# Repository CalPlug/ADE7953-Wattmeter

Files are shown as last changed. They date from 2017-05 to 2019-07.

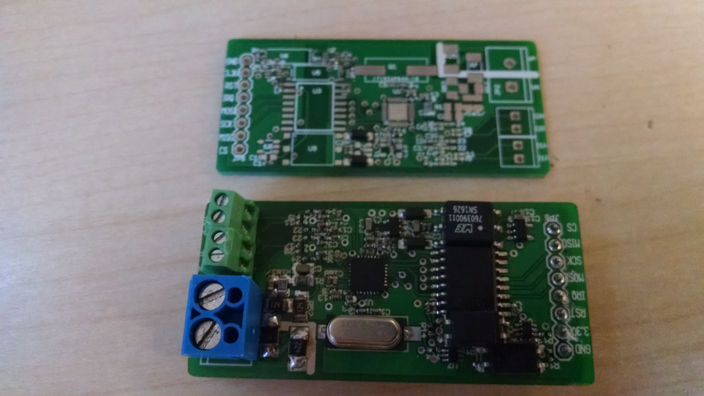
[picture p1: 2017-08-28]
Documents/PopulatedV2_Image.jpg

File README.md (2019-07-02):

# ADE7953-Wattmeter

Example Arduino compatable library for operating the Analog Devices ADE7953 Single-Phase AC Line measurement IC over SPI and I2C interfacing 

Arduino Uno / ESP8266 Library created by Umar Kazmi, Crystal Lai, and Michael Klopfer, Ph.D.

PCB v1 and v2 Board design by Damien Putignani (11/2016, 02/2017)

Version 3 PCB update by Yuxiang (Eric) Li	and Zihan (Bronco) Chen (11/2017)

Version 3.1 PCB update by Erica Deng (05/2018) - Isolation correction

Version 4 PCB (SPI / UART and I2C Variants) revision update by Erica Deng, Yongxi Li, Andy Begley, and Lifeng Liang (5/2018)

ESP32 SPI Extension Development by Luis Contreras as an extended part of the CalPlug EVSE Project (5/2018) - https://github.com/CalPlug/EVSE_Smart_Charger

University of California, Irvine - California Plug Load Research Center (CalPlug)

February 23, 2017 - SPI Library First Release

May 24, 2018 - I2C Library First Release, updated 12/2018

Updated PCB vervisions and notes 5/2019

Copyright (C) The Regents of the University of California, 2019

Released into the public domain under creative commons share-alike license. This is an example C++ library for Arduino for operating the ADE7953 Single-Phase AC Line measurement IC over SPI and tested with the Arduino Uno and C++ Arduino-style compiler for the Espressif ESP8266. This library in current form was shown to work with the Arduino Uno and the Espressif ESP8266.  See note below about Espressif ESP32 compatability - a working example is provided isn the ESP32 folder in this project.  This ESP32 extension example was developed by Luis Contreras as part of the CalPlug EVSE Project - https://github.com/CalPlug/EVSE_Smart_Charger and presented in this project as functional example working with the ESP32.

Installation
--------------------------------------------------------------------------------

To install this library, just place this entire folder as a subfolder in your
Arduino/lib/targets/libraries folder.
When installed, this library should look like:
Arduino/lib/targets/libraries/ADE7953              (this library's folder)
Arduino/lib/targets/libraries/ADE7953/ADE7953.cpp     (the library implementation file)
Arduino/lib/targets/libraries/ADE7953/ADE7953.h       (the library description file)
Arduino/lib/targets/libraries/ADE7953/examples     (the examples)
Arduino/lib/targets/libraries/ADE7953/readme.txt   (this file)

Note: as of 5/2018, the library has forked into an SPI and I2C variant that are tested with the ESP8266 and Atmel AVR.  There is also a known working SPI version for the ESP32.

Building
--------------------------------------------------------------------------------

After this library is installed, you can start the Arduino application.
You may see a few warning messages as it's built.
To use this library in a sketch, go to the Sketch | Import Library menu and select Test. This will add a corresponding line to the top of your sketch: #include <ADE7953.h>
To stop using this library, delete that line from your sketch.

Background of Operation
--------------------------------------------------------------------------------

The ADE7953 uses registers for communication.  Depending on the type, this can be an 8 bit, 16 bit, 24 bit or 32 bit register.  Communication of over 8 bits uses sequential bytes using typical SPI byte-wise communication.  There are redundancies in how registers are accessed via different bit values for registers.  For addresses, the same command may be represented in multiple bit versions (eg a 24bit or 32 bit). When you call on a certain address, the corresponding value is returned with the value bit size corresponding to the 24 or 32 bit address called on. The responding value returns as the function called and of the same bit size.  Refer to the documentation!  For Debug, the Serial Monitor runs at 115200 baudrate when the reporting DEBUG functionality is activated.  Uncomment IFDEF statements in the library for library operation debug. 

Usage
--------------------------------------------------------------------------------

There are several layers of functionality in the library.  Functions are defined to permit direct communication via registers of different bit sizes.  One can use the functions in this library for direct communication using the send and receive capability of the register calls or use direct functions.  The direct functions are also included. In order to access the functions, you must write in the Arduino file myADE7953.getFunction(), Function being the function you want such as Vrms or IrmsA (the different names of functions can be found in the .h file), while myADE7953 calls on the library. 

A sample I2C and SPI library for Arduino have been built and are present in this project.  At the present time the I2C is less developed than the SPI version.

Note: A varient of this project's code was shown to work on the Espressif ESP32, please see this project for more details:  https://github.com/CalPlug/EVSE_Smart_Charger

Calibration
--------------------------------------------------------------------------------
For a given hardware (register set) gain setting in the ADE7953 (we calibrate for each gain option in our final use code) we perform the calibration as inputs to each call of the decimalize() function for reported values:

0) Set a given HW gain value - this is important, each gain needs a different calibration set typically, also beware the input impedance can change for different hardware (register set) gain values!

1) We set values to gain = 1 and offset = 0 for each channel that will be calibrated.

2) Supply a known value and record returned values for all channels we are calibrating - this may be using a load that is measured by another calibrated meter so the current and voltage (or whatever basis parameters you care about are known).

3) In MS Excel (or Origin, Matlab, or any other program that can perform linear regression), we calculate the regression values (m (gain) and b (offset)) for y=mx+b, where y is the proper value, and x is the ADC returned value.  We take a number of measurements across the linear measurement range.  Typically the ADCs on this IC are very linear.  Keep in mind the r^2 value for the fitting is not all that matters - the distance between the fit line and the expected values (the residuals) will give you an idea of calibration gross accuracy across your measurement range. 

4) Enter gain and offset regression values for each calibrated input channel (overwriting the initial gain=1 and offset=0 values used in the calibration process), recompile, and test.

5) Repeat calibration process if your outputted values do not now closely match your expected measured values.

A sample calibration spreadsheet is provided:  https://github.com/CalPlug/ADE7953-Wattmeter/blob/master/library/LinearCalibrationCalculator.xls

Demo
--------------------------------------------------------------------------------

When connecting a 80-Watt Lightbulb with a 110V AC, 60HZ, source and using our demo code, the serial monitor reads out the following approximate measurements from the current sensor:

Vrms (V): 110

IrmsA (mA): 718

Apparent Power A (mW): 80000

Active Power A (mW): 80000

Reactive Power A (mW): 4100

Power Factor (div 100): 99.90

Active Energy A (hex): 5132 

See initial checkout instructions for the PCB for expected demo code output:  https://github.com/CalPlug/ADE7953-Wattmeter/blob/master/Documents/Construction%20of%20Wattmeter.pdf

Physical Demo Board
----------
This design is provided without any warranty or assumption of liability.  This project involves the use of mains voltage.  We have no idea how well you can reporduce this design: we assume no liability for your implementation or usage mistakes! Please construct and use at your own risk.

This folder contains all the files required to construct a fully isolated ADE7953 wattmeter board that uses SPI or UART communication (see IC Datasheet). Please refer to the README inside the folder for more details on using the files.  The Version 3 supercedes the Version 2 board.  Version 1 of this PCB was an internally produced breadboard evaualtion version of this design.  It was created only to be proceeded by Version 2.  In the Version 2 (preliminary release) revision, there is no tri-state on the MISO line on the external side of the isolation chipset. Because of this, the board works properly when it is the only device on the SPI bus. If more devices are used on the same SPI bus, the CS line (inverted) must be used to drive a tristate to isolate the MISO line from this board.  The RESET and IRQ lines can be left unconnected for general operation of the board - the ADE7953 reset line is held HIGH by a pullup by default.  The minimum connections required are the data and power lines.  Be cognizent that flipped L and N in this design can result in safety concerns - the neutral volatage should be very close to ground.  This issue is mediated in the following design revisions.  The Version 2 board has the neutral connected to the isolated ground.  In bench testing, this design worked well, but in general usage, several catostrophic board failures resulted (not that crazy on our part: look at how the Analog Devices datasheet and AD demo boards are wired :) ).  

Accordingly, a safer design was developed (Version 3).  As previously stated, the Version 2 of the board does not allow for multiple devices to be used on the SPI as the MISO line is held low when communication has ended (the isolator is always enabled, causing this).  In the updated Version 3, an inverted gate tri-state buffer allows proper SPI usage with multiple devices and resistor chains are used to isolate the neutral from the ground in case of the neutral having the voltage become raised substantially above the ground (or flipped with the line).  A ground isolation issue was resolved in Version 3.1 to improve the safety of the board further.  In Version 3.1 and forward there is full separation of the grounds on the isolated and non isolated sides of the board.

The Version 4 of this board allows use of a multiplexer for line and neutral inputs along with two current measurement coils to allow GFI detection.  The isolator configuration allows for fullly independant ground isolation.  The a jumper on this board (position 1-2, or position 2-3) allows the static setting of the line, or a pin (SELECT) can be used to toggle the voltage input being read (used with ground fault detection - full GFI implementation requires an interruptter!).  This can be used to set a single input pin for the line to measure against ground without needing a dedicated microcontroller pin or external connection.  Mind the phasing between the two coils if two CTs are used for GFI detection.  Implementation of the GFI detection and interruption with this design was demonstrated in this project using the Espressif ESP32: https://github.com/CalPlug/EVSE_Smart_Charger   The default version of this board (Version 4) is also UART compatable (see included documentation) in addition to SPI.  But the bidirectional nature of I2C prevents this working with the current isolation scheme.  An alternative design (Version 4 I2C) is also provided which permits I2C interfacing using the same board format.

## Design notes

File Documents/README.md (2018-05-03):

Note:

The boards (versions 2-4) will take 3.3 to 5V as an input DC power in per our tests.  More efficient operation is at 3.3V and what we typically use.  Preference to use 3.3V logic voltages but 5V tolerant - but output logic voltage will match supply!  Be Careful!
Mind the isolation capability of the isolator - avoid ground loops and large differences between grounds.  On V2 be careful as to the L/N orrientation for the AC input.  A second resistor divider network on V3 provides more protestion.  V4 uses a multiplexer in place of a set of networks to allow Ground Fault (GF) detection as part of a potential GFI system.

File Manifest: 

Wattmeter_v2_gerber_files.zip
------------------------------
Upload this .zip file to https://www.smart-prototyping.com/PCB-Prototyping.html to order PCBs for populating.

wattemeterBOM.xlsx (in Wattmeter_V2 Folder)
-------------------
This spreadsheet is the bill of materials for populating the PCBs.

Wattmeter_v2.brd & Wattmeter_v2.sch (in Wattmeter_V2 Folder)
------------------------------------
Open them with EagleCAD and print them out, and have them nearby while populating the PCBs to know what goes where.

Construction of Wattmeter.pdf and Stilting Components to a PCB_in_V2_MJKedit.docx and WattmeterCheckoutGuide
-----------------------------
Documents showing assembly and test procedures.
Shows what a finished Wattmeter looks like, and has some important tips on populating the PCBs.  

NOTE: There is no tri-state on the MISO line in board Version 2.  This is added into the next board revision (Board version 3.  Because of this, the board works properly when it is the only device on the SPI bus.  If more devices are used on the same SPI bus, the CS line (inverted) must be used to drive a tristate to isolate the MISO line from this board!!! 

PopulatedV2_Image.jpg
-----------------------------
Image of the blank and populated PCB of the wattmeter

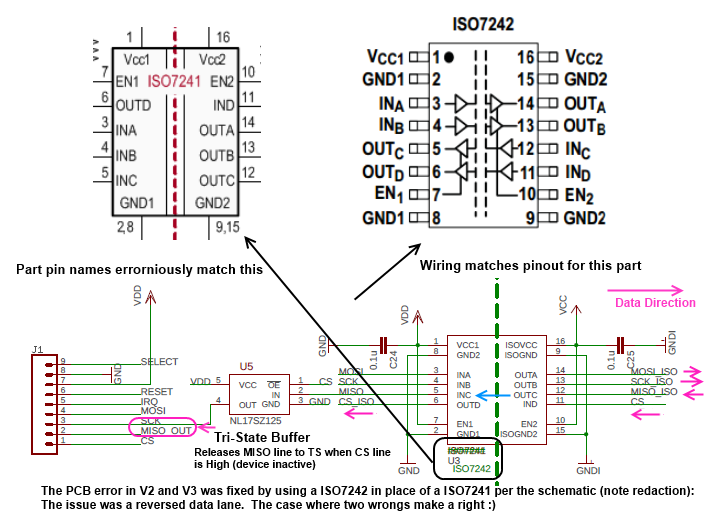
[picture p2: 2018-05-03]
Documents/V2_V3Error.png

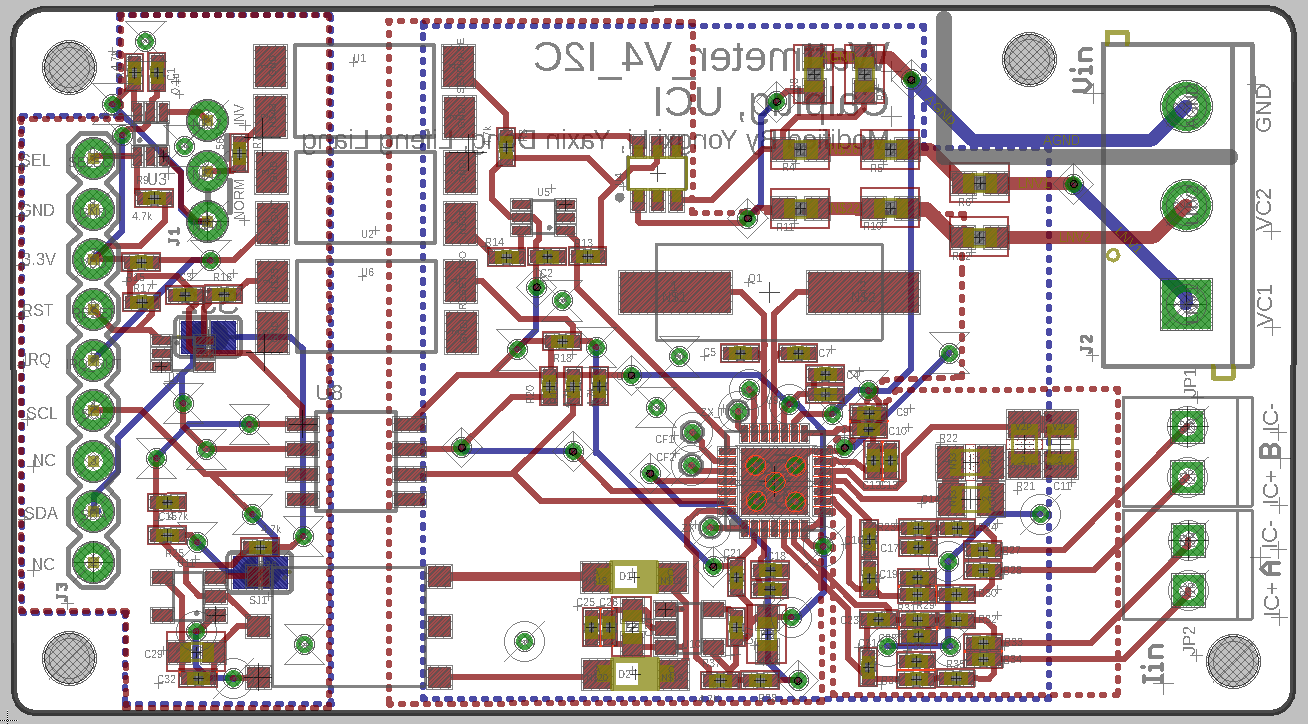
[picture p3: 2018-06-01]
documents/Wattmeter_V4/Wattmeter_V4_I2C.PNG

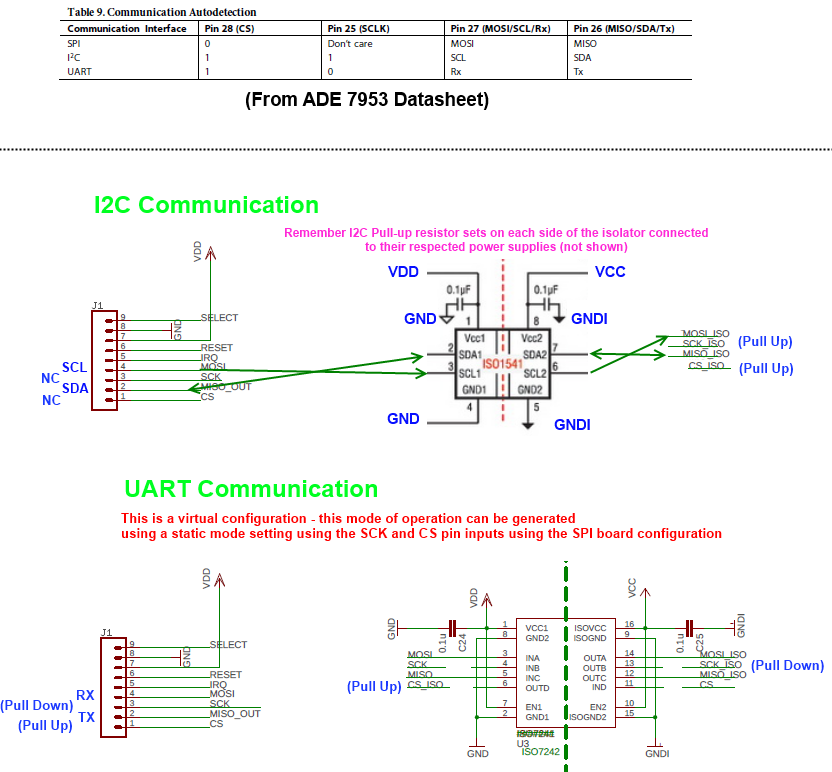
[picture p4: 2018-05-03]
pcb_layout/Wattmeter_V4/UARTandSPICom.png

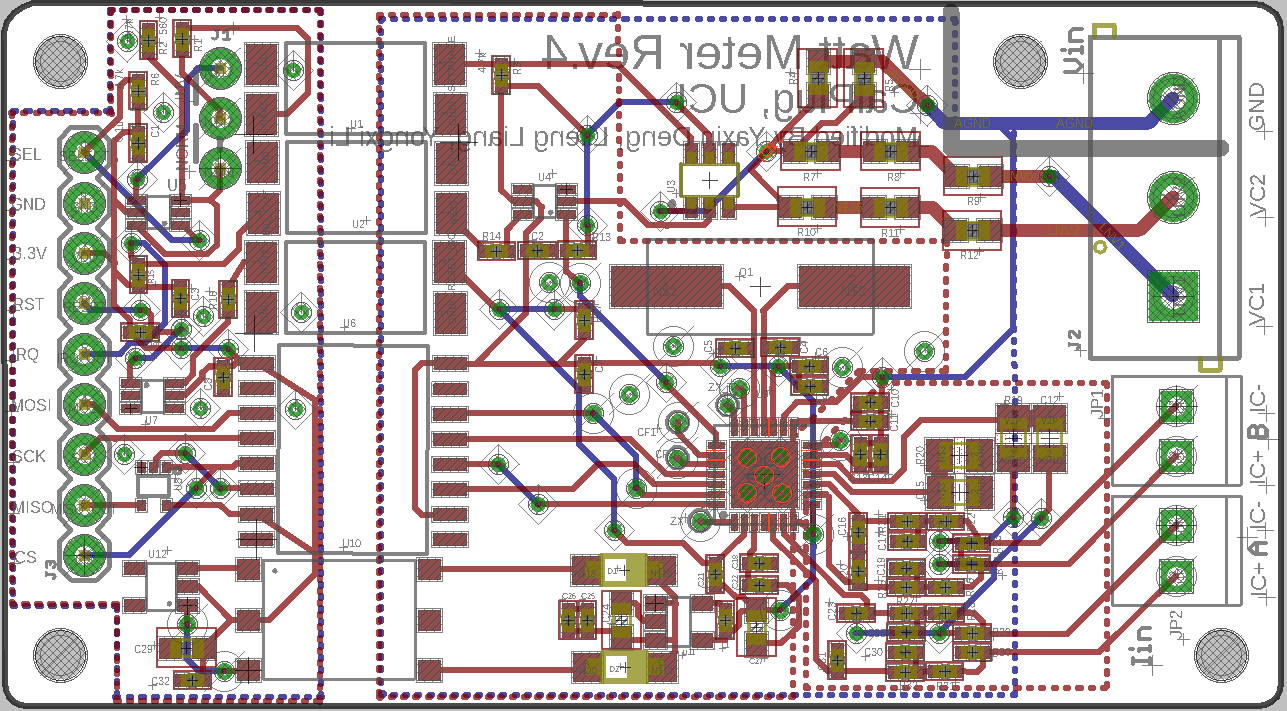
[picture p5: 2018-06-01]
documents/Wattmeter_V4/Wattmeter_V4.PNG

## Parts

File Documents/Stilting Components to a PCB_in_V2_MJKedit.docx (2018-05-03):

Stilting Components to a PCB

Jazmin Villegas

California Plug Load Research Center

1. What is stilting?

Stilting is the process of attaching/soldering legs to a component in order to elevating the component by a desired height. This is a process to allow testing of a component where the packaging was not intended for mounting on the PCB that mounting will occur. Typically the PCB was intended for a smaller package component. Vertical height is used to compensate for lack of lateral space with component placement. In this case two opto-isolators are too close to be mounted properly. Both parts are stilted to permit mounting without interference.

2. Why so you need to stilt?

U5 U6

When applying components to a printed circuit board (PCB) you may find that there is a crowd of components in a certain area, resulting in component-component interference. This may not allow you to use the conventional methods of soldering or the soldering paste as you have intended. As shown in the picture on the right, components U6 and U5 had been placed in close proximity to one another, not allowing for either to be placed properly on the pads intended for connections to this component. With stilting we will be able to elevate one component (or both) allowing for proper connectivity of all components.

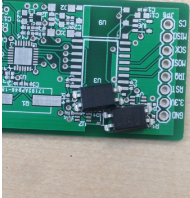
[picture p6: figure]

Figure 1: Neither U6 nor U5 are able to align with the pads on the PCB. Both components have four legs.

3. How to Stilt.

To beginning the process of stilting you will need to make sure your component is sanitized and fully functional.

  i. First, we will begin by applying a metal stilt to each leg. Use the cut leads from a 1/4th watt resistor as the interconnect leads. Having malleable stilts allows you to freely adjust your component for the best allignment to pads while preventing interference on the board. These legs are generally tin-clad copper wire. When applying the metal, you would like to measure how much height is needed to allow best allignment. In our case, we only needed one component stilted with the height being more than its bordering components. Make sure all legs are cut to the proper height before soldering, a final trimming will occur after soldering each leg to the part to mount.
  ii. After you have measured and trimmed all the stilts for your component, you can now solder each stilt to a corresponding leg. Use tweezers to hold part when soldering to prevent burs. Tin both the component and the wire before performing the joining via soldering. When you finish soldering check the height of the stilts once again, if the stilts have shifted in height cut the appropriate amount of metal from the stilts so the component can lay on a flat surface. The stilts should align with the pads and the component should sit flat on the stilts. Do not mount to some pads and warp the other legs to meet remaining pads. It is easy to tear pads off the PCB when doing this.
  iii. Next you would like to position your component on your PCB ensuring that all stilts are placed on top of the corresponding solder pads. Soldering the stilt to the board will be a bit challenging. You will need to quickly apply solder each leg, the heat from the solder iron may loosen your any previous soldering you have completed. If this does happen reapply the loose piece(s) once again. Once you have completed applying all legs you would like to repeat this process for any other parts you would like stilted or continue soldering the rest of your other components.

Stilted Component

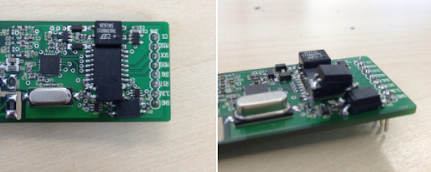
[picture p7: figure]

Figure 2: A finished PCB after stilting. The picture on the left is the top view. The picture on the right is the side view. Here you notice the component we have stilted. It is elevated above the components in its proximity allowing for the other components to lay flat on the PCB.

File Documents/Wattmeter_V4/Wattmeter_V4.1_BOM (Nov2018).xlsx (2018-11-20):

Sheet: DIGIKEY
Qty | Value | Device | Package | Parts | DIGIKEY | Unit Price | Total quantity | Total price
11 | 0.1u | 0402-CAP | 0402-CAP | C1,C2,C3,C7,C8,C9,C11,C14,C18,C26,C32 | http://www.digikey.com/product-detail/en/GRM155R61A104KA01D/490-1318-1-ND/587923 | 0.007 | 110 | 16.599
2 | 20p | 0402-CAP | 0402-CAP | C4,C5 | http://www.digikey.com/product-detail/en/murata-electronics-north-america/GJM1555C1H200FB01D/490-11204-1-ND/5333044 | 0.12 | 20 | 2.4
4 | 4.7u | 0402-CAP | 0402-CAP | C6,C10,C13,C22 | http://www.digikey.com/product-detail/en/GRM155R60J475ME87D/490-5408-1-ND/2175215 | 0.126 | 40 | 5.4
2 | 0.033uF | C-EUC0805K | C0805K | C12,C15 | http://www.digikey.com/product-detail/en/samsung-electro-mechanics-america-inc/CL05B333KO5NNNC/1276-1177-1-ND/3889263 | 0.028 | 20 | 0.56
8 | 33n | 0402-CAP | 0402-CAP | C16,C17,C19,C20,C23,C28,C30,C31 | http://www.digikey.com/product-detail/en/samsung-electro-mechanics-america-inc/CL05B333KO5NNNC/1276-1177-1-ND/3889263 | 0.162 | 80 | 12.96
2 | 1u | 0402-CAP | 0402-CAP | C21,C25 | https://www.digikey.com/products/en?keywords=445-9082-1-ND | 0.12 | 20 | 2.4
2 | 10uF | C-USC0603 | C0603 | C24,C27 | https://www.digikey.com/product-detail/en/murata-electronics-north-america/GRM188R60J106ME47D/490-3896-1-ND/965938 | 0.14 | 20 | 2.8
1 | 10uF TANT | C-USC0603 | C0603 | C29 | https://www.digikey.com/product-detail/en/vishay-sprague/T58MM106M6R3C0500/718-2110-1-ND/5844728 | 0.528 | 10 | 5.28
2 | MBR0520LT | MBR0520LT | SOD123 | D1,D2 | https://www.digikey.com/product-detail/en/micro-commercial-co/MBR0520-TP/MBR0520TPMSCT-ND/717365 | 0.292 | 20 | 5.84
12 |  | CONN_09 | 1X3, 1X9 | J1,J3 | https://www.digikey.com/products/en?mpart=PREC040SAAN-RC&v=35 | 0.51 | 3 | 1.53
1 |  | CONN_03-SCREW-5MM | SCREWTERMINAL-5MM-3 MULTI | J2 | https://www.digikey.com/product-detail/en/phoenix-contact/1729021/277-1237-ND/260605 | 1.507 | 10 | 15.07
2 |  | M022.54MM_SCREWTERM | 1X02_2.54_SCREWTERM | JP1,JP2 | https://www.digikey.com/product-detail/en/on-shore-technology-inc/OSTVN02A150/ED10561-ND/1588862 | 0.568 | 20 | 11.36
1 | 15nH | IND0402 | 0402-RES | L1 | https://www.digikey.com/product-detail/en/murata-electronics-north-america/LQG15HS15NJ02D/490-2625-1-ND/662905 | 0.061 | 10 | 0.61
1 | QUARTZ_3.58M_2PIN | QUARTZ_3.58M_2PIN | HC-49S | Q1 | https://www.digikey.com/product-detail/en/txc-corporation/9C-3.579545MBBK-T/887-2450-1-ND/4475440 | 0.303 | 10 | 3.03
3 | 560 | 0402-RES | 0402-RES | R1, R14, R16 | http://www.digikey.com/product-detail/en/panasonic-electronic-components/ERJ-2RKF5600X/P560LCT-ND/1746701 | 0.043 | 30 | 1.29
7 | 4.7k | 0402-RES | 0402-RES | R2,R3,R6,R13,R15,R17,R18 | https://www.digikey.com/product-detail/en/panasonic-electronic-components/ERJ-2GEJ472X/P4.7KJCT-ND/147025 | 0.029 | 90 | 2.61
2 | 4.7k | RESISTOR0603-RES | 0603-RES | R4,R5 | https://www.digikey.com/product-detail/en/vishay-dale/TNPW06034K75BEEA/TNP4.75KAATR-ND/1606844 | 0.116 | 20 | 2.32
2 | 55k | RESISTOR0603-RES | 0603-RES | R7,R10 | https://www.digikey.com/products/en?keywords=RMCF0603FT54K9CT-ND | 0.017 | 20 | 0.34
4 | 100k | RESISTOR0603-RES | 0603-RES | R8,R9,R11,R12 | https://www.digikey.com/products/en?keywords=P100KHCT-ND | 0.063 | 40 | 2.52
2 | 1k | R-EU_ | C0805K@1 | R19,R20 | https://www.digikey.com/products/en?keywords=A106056CT-ND | 0.032 | 20 | 0.64
4 | 1k | 0402-RES | 0402-RES | R21, R25, R27, R32 | https://www.digikey.com/products/en?keywords=P1.00KLCT-ND | 0.043 | 40 | 1.72
4 | 100 | 0402-RES | 0402-RES | R22,R26, R28,R31 | http://www.digikey.com/product-detail/en/panasonic-electronic-components/ERJ-2RKF1000X/P100LCT-ND/194126 | 0.043 | 40 | 1.72
4 | 51 | 0402-RES | 0402-RES | R23,R24,R29,R30 | http://www.digikey.com/product-detail/en/panasonic-electronic-components/ERJ-2RKF51R0X/P51.0LCT-ND/1746700 | 0.043 | 40 | 1.72
3 | PS2505 | PS2505 | PS2505 | U1, U2,U6 | http://www.digikey.com/product-detail/en/cel/PS2505L-1-F3-A/PS2505L-1-F3-ACT-ND/3646235 | 0.732 | 30 | 21.96
1 | SN74LVC1G3157DBVR | SN74LVC1G3157DBVR | SOT-23-6 | U3 | https://www.digikey.com/products/en?keywords=296-14908-1-ND | 0.276 | 10 | 2.76
3 | SN74LVC | SN74LVC | DCKT | U4, U5,U7 | http://www.digikey.com/product-detail/en/texas-instruments/SN74LVC2G14DCKT/296-26619-1-ND/2255077 | 0.869 | 30 | 26.07
1 | NL17SZ125 | NL17SZ125 | NL17SZ125 | U8 | https://www.digikey.com/product-detail/en/on-semiconductor/NL17SZ125DFT2G/NL17SZ125DFT2GOSCT-ND/1139962 | 0.276 | 10 | 2.76
1 | ADE7953 | ADE7953 | 28-WFQFN | U9 | http://www.digikey.com/product-detail/en/analog-devices-inc/ADE7953ACPZ/ADE7953ACPZ-ND/2700176 | 3.594 | 10 | 35.94
1 | ISO7241 | ISO7241 | 16-SOIC | U10 | http://www.digikey.com/product-detail/en/texas-instruments/ISO7241CDWR/296-37636-1-ND/4833880 | 4.466 | 10 | 44.66
1 | PAM2305 | PAM2305 | TSOT25 | U11 | http://www.digikey.com/product-detail/en/diodes-incorporated/PAM2305AAB330/PAM2305AAB330DICT-ND/5267111 | 0.51 | 10 | 5.1
1 | SN6501 | SN6501 | SOT-23-5 | U12 | http://www.digikey.com/product-detail/en/texas-instruments/SN6501DBVR/296-37700-1-ND/4833928 | 1.801 | 10 | 18.01
1 | TRANSFO_3.3 | TRANSFO_3.3 | TRANSFO_3.3 | U13 | http://www.digikey.com/product-detail/en/wurth-electronics-midcom/760390011/732-4455-1-ND/3831291 | 1.71 | 10 | 17.1
 |  |  |  |  |  |  | TOTAL PRICE: | 275.079

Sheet: AMAZON
Qty | Value | Device | Package | Parts | Amazon | Unit Price | Total quantity | Total price
1 |  | jumper cap |  |  | https://www.amazon.com/gp/offer-listing/B00008VF46/ref=dp_olp_new_mbc?ie=UTF8&condition=new | 6 | 1 | 6
 |  |  |  |  |  |  | total price | 6

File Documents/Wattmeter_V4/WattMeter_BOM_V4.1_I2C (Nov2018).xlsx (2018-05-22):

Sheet: Feuil1
Qty | Value | Device | Package | Parts | DIGIKEY | Unit PRICE | Total quantity | Total price
2 |  | M022.54MM_SCREWTERM | 1X02_2.54_SCREWTERM | JP1,JP2 | ED10561-ND | 0.568 | 20 | 11.36
11 | 0.1u | 0402-CAP | 0402-CAP | C1,C2,C3,C6,C8,C10,C13,C15,C18,C25,C32 | 445-1265-6-ND | 0.08755 | 110 | 9.6305
4 | 100 | 0402-RES | 0402-RES | R24,R30,R32,R35 | P100LCT-ND | 0.043 | 40 | 1.72
2 | 10uF | C-USC0603 | C0603 | C24,C27 | 490-3896-1-ND | 0.14 | 20 | 2.8
1 | 15nH | IND0402 | 0402-RES | L1 | 445-3061-1-ND | 0.052 | 10 | 0.52
4 | 1k | 0402-RES | 0402-RES | R23,R29,R31,R36 | P1.00KLCT-ND | 0.043 | 40 | 1.72
2 | 1u | 0402-CAP | 0402-CAP | C21,C26 | 445-9082-1-ND | 0.12 | 20 | 2.4
2 | 20p | 0402-CAP | 0402-CAP | C5,C7 | 490-11204-1-ND | 0.162 | 20 | 3.24
2 | 0.033uF | C-EUC0805K | C0805K | C11,C14 | 445-2675-2-ND | 0.359 | 20 | 7.18
4 | 4.7u | 0402-CAP | 0402-CAP | C4,C9,C12,C22 | 399-5499-1-ND | 0.28 | 40 | 11.2
4 | 51 | 0402-RES | 0402-RES | R27,R28,R33,R34 | P51.0LCT-ND | 0.043 | 40 | 1.72
3 | 560 | 0402-RES | 0402-RES | R7,R14,R16 | P560LCT-ND | 0.043 | 30 | 1.29
1 | ADE7953 | ADE7953 | 28-WFQFN | U9 | ADE7953ACPZ-ND | 3.594 | 10 | 35.94
2 | MBR0520LT | MBR0520LT | SOD123 | D1,D2 | MBR0520LCT-ND | 0.323 | 20 | 6.46
1 | PAM2305 | PAM2305 | TSOT25 | U10 | PAM2305AAB330DICT-ND | 0.51 | 10 | 5.1
1 | QUARTZ_3.58M_2PIN | QUARTZ_3.58M_2PIN | HC-49S | Q1 | 887-2450-1-ND(out of stock) | 0.303 | 10 | 3.03
1 | SN6501 | SN6501 | SOT-23-5 | U11 | 296-37700-1-ND | 1.801 | 10 | 18.01
3 | SN74LVC | SN74LVC | DCKT | U3,U5,U7 | 296-26619-1-ND | 0.869 | 30 | 26.07
1 | TRANSFO_3.3 | TRANSFO_3.3 | TRANSFO_3.3 | U12 | 732-4455-1-ND | 1.71 | 10 | 17.1
13 | 4.7k | 0402-RES | 0402-RES | R1,R3,R9,R13,R15,R17,R18,R19,R20,R25,R26,R37,R38 | P10.0KLCT-ND | 0.0176 | 130 | 2.288
1 | 10uF-TANT | C-USC0603 | C0603 | C29 | 718-2110-1-ND | 0.528 | 10 | 5.28
8 | 33nF | 0402-CAP | 0402-CAP | C16,C17,C19,C20,C23,C28,C30,C31 | 399-8964-6-ND | 0.4795 | 80 | 38.36
1 | JUMPER3 | JUMPER3 | 1X03 | J1,J3 | S1012EC-40-ND | 0.454 | 10 | 4.54
1 |  | CONN_03-SCREW-5MM | SCREWTERMINAL-5MM-3 | J2 | 277-1237-ND | 1.507 | 10 | 15.07
2 | 4.7k | RESISTOR0603-RES | 0603-RES | R2,R8 | A106050DKR-ND | 0.368 | 20 | 7.36
2 | 55k | RESISTOR0603-RES | 0603-RES | R4,R11 | RMCF0603FT54K9CT-ND | 0.017 | 20 | 0.34
4 | 100k | RESISTOR0603-RES | 0603-RES | R5,R6,R10,R12 | P100KHCT-ND | 0.063 | 40 | 2.52
2 | 1k | R-EU_ | C0805K@1 | R21,R22 | A106056CT-ND | 0.032 | 20 | 0.64
3 | PS2505 | PS2505 | PS2505 | U1,U2,U6 | PS2505L-1-F3-ACT-ND | 0.606 | 30 | 18.18
1 | SN74LVC1G3157DBVR | SN74LVC1G3157DBVR | SOT-23-6 | U4 | 296-14908-1-ND | 0.276 | 10 | 2.76
1 | ISO1541 | ISO1541 | ISO1541 | U8 | 296-34872-1-ND | 3.883 | 10 | 38.83
 |  |  |  |  |  |  | Total: | 302.66

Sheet: Feuil1 (2)
Qty | Value | Device | Package | Parts | DIGIKEY | Unit PRICE for 10 | Total quantity (15 boards) | Qty in stock | Qty to buy | Total price
2 |  | M022.54MM_SCREWTERM | 1X02_2.54_SCREWTERM | JP3, JP4 | http://www.digikey.com/product-detail/en/on-shore-technology-inc/OSTVN02A150/ED10561-ND/1588862 | 0.568 | 30 | 9 | 21 | 11.928
1 |  | M025MM | SCREWTERMINAL-5MM-2 | JP2 | https://www.digikey.com/product-detail/en/1729018/277-1236-ND/260604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 | 0.955 | 15 | 4 | 11 | 10.505
1 |  | M08 | 1X08_ROUND | JP5 | no componant | 0 | 15 |  | 15 | 0
10 | 0.1u | 0402-CAP | 0402-CAP | C4, C8, C14, C16, C18, C20, C24, C25, C26, C27 | http://www.digikey.com/product-detail/en/GRM155R61A104KA01D/490-1318-1-ND/587923 | 0.014 | 150 |  | 150 | 2.1
4 | 100 | 0402-RES | 0402-RES | R21, R22, R23, R24 | http://www.digikey.com/product-detail/en/panasonic-electronic-components/ERJ-2RKF1000X/P100LCT-ND/194126 | 0.028 | 60 | 37 | 23 | 0.644
5 | 10k | 0402-RES | 0402-RES | R2, R3, R13, R14, R15 | https://www.digikey.com/product-detail/en/yageo/RC0402FR-0710KL/311-10.0KLRCT-ND/729470 | 0.014 | 75 |  | 75 | 1.05
2 | 10uF | C-USC0603 | C0603 | C22, C23 | https://www.digikey.com/product-detail/en/murata-electronics-north-america/GRM188R60J106ME47D/490-3896-1-ND/965938 | 0.123 | 30 |  | 30 | 3.69
2 | 120k | R-EU_M1206 | M1206 | R12, R52 | http://www.digikey.com/product-detail/en/yageo/RC1206JR-07120KL/311-120KERCT-ND/732163 | 0.024 | 30 | 19 | 11 | 0.264
1 | 15nH | IND0402 | 0402-RES | L1 | https://www.digikey.com/product-detail/en/murata-electronics-north-america/LQG15HS15NJ02D/490-2625-1-ND/662905 | 0.061 | 15 | 2 | 13 | 0.793
4 | 1k | 0402-RES | 0402-RES | R4, R5, R6, R8 | https://www.digikey.com/product-detail/en/yageo/RC0402FR-071KL/311-1.00KLRCT-ND/729460 | 0.014 | 60 | 38 | 22 | 0.308
2 | 1u | 0402-CAP | 0402-CAP | C9, C21 | https://www.digikey.com/product-detail/en/avx-corporation/04026D105MAT2A/478-5315-1-ND/1950982 | 0.184 | 30 | 15 | 15 | 2.76
2 | 20p | 0402-CAP | 0402-CAP | C1, C2 | http://www.digikey.com/product-detail/en/murata-electronics-north-america/GJM1555C1H200FB01D/490-11204-1-ND/5333044 | 0.162 | 30 |  | 30 | 4.86
4 | 220k | R-EU_R2010 | R2010 | R7, R25,R28,R29 | https://www.digikey.com/product-detail/en/panasonic-electronic-components/ERJ-12ZYJ224U/P220KWCT-ND/249767 | 0.245 | 60 | 25 | 35 | 8.575
8 | 33n | 0402-CAP | 0402-CAP | C5, C6, C11, C12, C28, C29, C30, C31 | http://www.digikey.com/product-detail/en/samsung-electro-mechanics-america-inc/CL05B333KO5NNNC/1276-1177-1-ND/3889263 | 0.024 | 120 |  | 120 | 2.88
4 | 4.7u | 0402-CAP | 0402-CAP | C3, C10, C13, C15 | http://www.digikey.com/product-detail/en/GRM155R60J475ME87D/490-5408-1-ND/2175215 | 0.111 | 60 |  | 60 | 6.66
2 | 499R | R-EU_ | C0805K@1 | R18, R19 | http://www.digikey.com/product-detail/en/susumu/RR1220P-4990-D-M/RR12P499DCT-ND/433096 | 0.098 | 30 | 17 | 13 | 1.274
4 | 51 | 0402-RES | 0402-RES | R9, R11, R17, R20 | http://www.digikey.com/product-detail/en/panasonic-electronic-components/ERJ-2RKF51R0X/P51.0LCT-ND/1746700 | 0.028 | 60 | 35 | 25 | 0.7
2 | 560 | 0402-RES | 0402-RES | R1, R10 | http://www.digikey.com/product-detail/en/panasonic-electronic-components/ERJ-2RKF5600X/P560LCT-ND/1746701 | 0.028 | 30 | 32 | 0 | 0
2 | 68nF | C-EUC0805K | C0805K | C7, C17 | http://www.digikey.com/product-detail/en/wurth-electronics-inc/885012207097/732-8079-1-ND/5454706 | 0.061 | 30 | 98 | 0 | 0
1 | ADE7953 | ADE7953 | 28-WFQFN | U1 | http://www.digikey.com/product-detail/en/analog-devices-inc/ADE7953ACPZ/ADE7953ACPZ-ND/2700176 | 3.63 | 15 |  | 15 | 54.45
1 | ISO7241 | ISO7241 | 16-SOIC | U3 | http://www.digikey.com/product-detail/en/texas-instruments/ISO7241CDWR/296-37636-1-ND/4833880 | 4.567 | 15 | 6 | 9 | 41.103
2 | MBR0520LT | MBR0520LT | SOD123 | D1, D2 | https://www.digikey.com/product-detail/en/micro-commercial-co/MBR0520-TP/MBR0520TPMSCT-ND/717365 | 0.292 | 30 | 7 | 23 | 6.716
1 | PAM2305 | PAM2305 | TSOT25 | U2 | http://www.digikey.com/product-detail/en/diodes-incorporated/PAM2305AAB330/PAM2305AAB330DICT-ND/5267111 | 0.51 | 15 | 4 | 11 | 5.61
2 | PS2505 | PS2505 | 4-SMD | U5, U6 | http://www.digikey.com/product-detail/en/cel/PS2505L-1-F3-A/PS2505L-1-F3-ACT-ND/3646235 | 0.732 | 30 | 38 | 0 | 0
1 | QUARTZ_3.58M_2PIN | QUARTZ_3.58M_2PIN | HC-49S | Q1 | http://www.digikey.com/product-detail/en/txc-corporation/9C-3.579545MBBK-T/887-2450-1-ND/4475440 | 0.303 | 15 | 7 | 8 | 2.424
1 | SN6501 | SN6501 | SOT-23-5 | U8 | http://www.digikey.com/product-detail/en/texas-instruments/SN6501DBVR/296-37700-1-ND/4833928 | 1.965 | 15 | 4 | 11 | 21.615
2 | SN74LVC | SN74LVC | DCKT | U4, U7 | http://www.digikey.com/product-detail/en/texas-instruments/SN74LVC2G14DCKT/296-26619-1-ND/2255077 | 0.82 | 30 | 8 | 22 | 18.04
1 | TRANSFO_3.3 | TRANSFO_3.3 | TRANSFO_3.3 | U9 | http://www.digikey.com/product-detail/en/wurth-electronics-midcom/760390011/732-4455-1-ND/3831291 | 1.71 | 15 | 5 | 10 | 17.1
1 | 4.7k | 0402-RES | 0402-RES | R16 | https://www.digikey.com/product-detail/en/panasonic-electronic-components/ERJ-2GEJ472X/P4.7KJCT-ND/147025 | 0.02 | 15 |  | 15 | 0.3
1 | 10uF-TANT | C-USC0603 | C0603 | C19 | https://www.digikey.com/product-detail/en/vishay-sprague/T58MM106M6R3C0500/718-2110-1-ND/5844728 | 0.528 | 15 |  | 15 | 7.92
1 | BUFFER-NL17SZ125 | BUFFER-NL17SZ125 | TSOP-5 | U$1 | https://www.digikey.com/product-detail/en/on-semiconductor/NL17SZ125DFT2G/NL17SZ125DFT2GOSCT-ND/1139962 | 0.28 | 15 |  | 15 | 4.2
 |  |  |  |  |  |  | TOTAL |  |  | 238.469

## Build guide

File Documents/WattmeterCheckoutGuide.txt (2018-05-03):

1) Populate all components, double check directions for the population, make notes to help with population as needed that can assist others to assist you.  Go easy on the solder for the QFN package IC (U1 on the schematic). You can use a touch more solder paste for the rest of the parts than previously used.  Take pictures as you assemble the next one as a guide.  Use the microscope for shots also.

2) After baking to fuse solder paste, put board under microscope and fully re-inspect all parts for good solder joints and proper component orientation. Especially inspect QFN package for solder quality at its edges. 

3) If necessary, stilt and mount remaining components that cause interference issues (like U5 on the schematic. We need to see if we can find smaller packages that can properly fit). 

4) Plug board into 3.3V source to power with no other connections.  Power draw should be substantially less than 0.75mA at 3.3V.  If this is not the case, components are likely mis-populated or bad, check component orientations and retest.  If anything is getting hot, check its orientation or replace, if a board continues to fail this test, kick it out and notify Mike or myself.  Mis-populated parts caused problems intitially for this design, verify everything multiple times.

5) Check voltage at the isolated bus between isolated ground and isolated V+, this should be 3.3V  

6) Using a good oscilloscope (not the pocket one). Verify the oscillation of the on-board crystal oscillator by measuring between isolated ground and each side of the crystal.  Oscillation should produce a nice sine wave at approximately 3.7 MHz between 0.5 and 3V in p-p amplitude. 

7) Test the IRQ and RESET isolation circuits by directly testing the reset.  Verify the line from the optoisolator for RESET to the chip is HIGH in normal intended operation.  IRQ is currently unused, we will come up with a testing plan for this next.  

8) Setup the I2C demo circuit and arduino code, verify I2C communication "pulses" on the SDA and SCL line feeding the board.  This code just tries to set up the IC for communication in a rapid loop.  On the isolated side, (grounding the scope to the isolated ground) look for "false response bit". This is a tell tale sign the chip is trying to respond to the input (with an ACK) but this return signal is being blocked by the unidirectional isolator.  This is proof positive the chip is operational and responding to input.  This is a quick check to verify IC is operational.  Until further notice, use external 3.3V power supply.  Verify 3.3V is outputted stability before connecting board.

9) Perform the modification to swap the MISO and CS pins on both sides of the isolator (more details here to follow after we try this for the first one).

10) Connect Board in SPI test setup with Arduino.  Use the code that reports "silicon version" "period" and "RMSvoltage" Connect function generator outputting 60 hz, 5V at 0V offset into the blue screw header.  Change frequency from 30 to 100 Hz, verify the period value changes accordingly.  This is the final QC step currently, more will follow once we begin calibration.

You should be familiar with all the steps except 8, 9, and, 10. I will show those three steps to you in person, but get started with the steps before that. Have a USB flash drive with you so that you can save waveforms as JPEGs from the oscilloscope.

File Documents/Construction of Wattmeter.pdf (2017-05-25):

## CalPlug Wattmeter

Parent Project: Projector Buddy

Umar Kazmi

March 24, 2016

Introduction

The CalPlug Wattmeter has been been developed to work with Projector Buddy and other projects. At its current state, the wattmeter measures RMS voltage and current, apparent, active, and reactive powers, and power factor. Atmel microcontrollers can be used to communicate with the wattmeter using the Serial Peripheral Interface (SPI) protocol. A library has been created to facilitate the integration of the wattmeter with the rest of the project.

Methods

The CalPlug Wattmeter based on the ADE7953 IC by Texas Instruments is shown below is in Figure 1. The schematic of the wattmeter is shown in Appendix A.

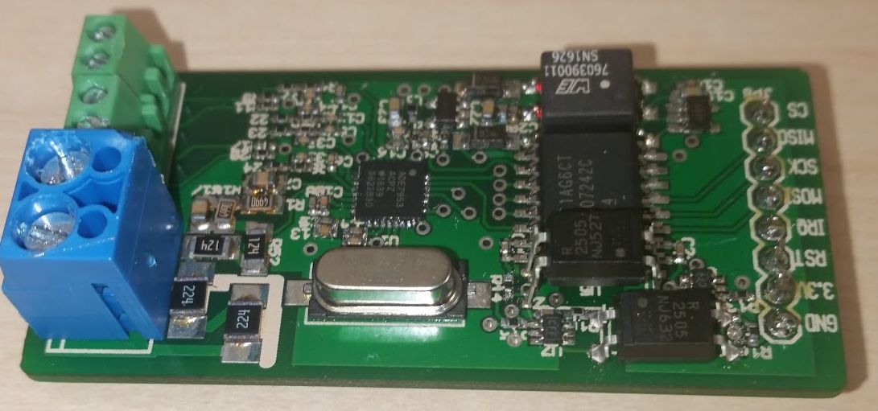
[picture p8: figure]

Figure 1: CalPlug Wattmeter

Care has to be taken when working with the pads of the ADE7953. The pads are narrow and can get shorted when soldering the IC in its place. To prevent that from happening, the pads are tinned. First, soldering paste is applied to the pads for the IC on the PCB. Then a heat gun is set to 350°C, and minimum air speed, and heat is applied for about 30 seconds for tinning. After the heat is removed, and if any two pads are shorted, the tip of a hot soldering iron can remove the excess solder from between pads. The process is repeated with the pads under the ADE7953 itself. Then the chip is placed and oriented on the PCB. No more soldering paste is applied. Then heat is again applied using the heat gun with the same settings. These are the steps required to place the IC on the PCB to ensure good contact. Figure 2 shows the ADE7953 IC making good contact with the pads on the PCB after tinning is done.

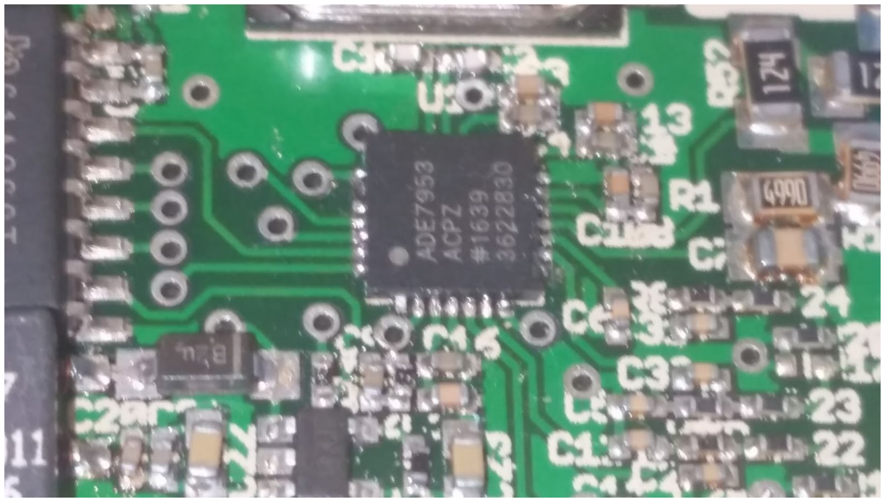
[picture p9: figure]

Figure 2: ADE7953 IC on tinned pads

Some boards were not tinned properly, before they were placed on the PCB. That resulted in the IC not being able to communicate with the Atmel microcontroller. In that case, a heat gun and a pair of tweezers are used to take the IC off of the board. Then the above steps are followed to place the IC on the board.

The slot for the isolator for the RESET pin, U5 on the schematic, is not large enough to accommodate it. So a stilted version of the same isolator is used, as shown in Figure 3. A drawback of using a stilted component is that if it is subjected to any pressure, it can come off. Not only that, it can tear the pad off of the board as well, as show in Figure 4. If that happens, the isolator can’t be soldered onto the board anymore. In that case the RESET is connected to the appropriate input of the IC directly through wet-wiring as shown in Figure 5.

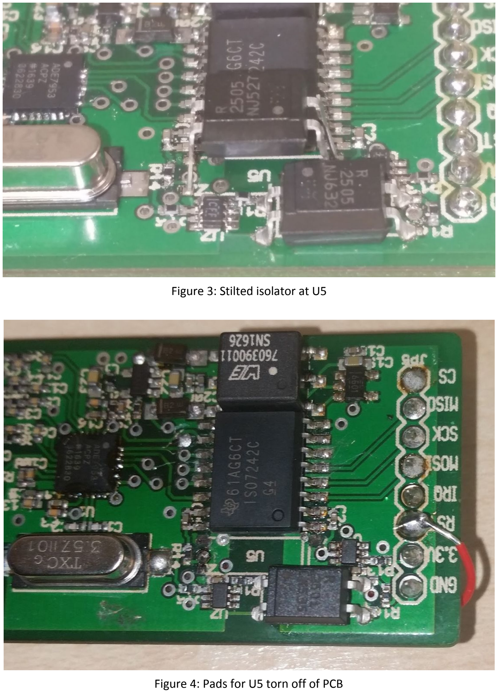
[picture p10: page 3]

Figure 3: Stilted isolator at U5

Figure 4: Pads for U5 torn off of PCB

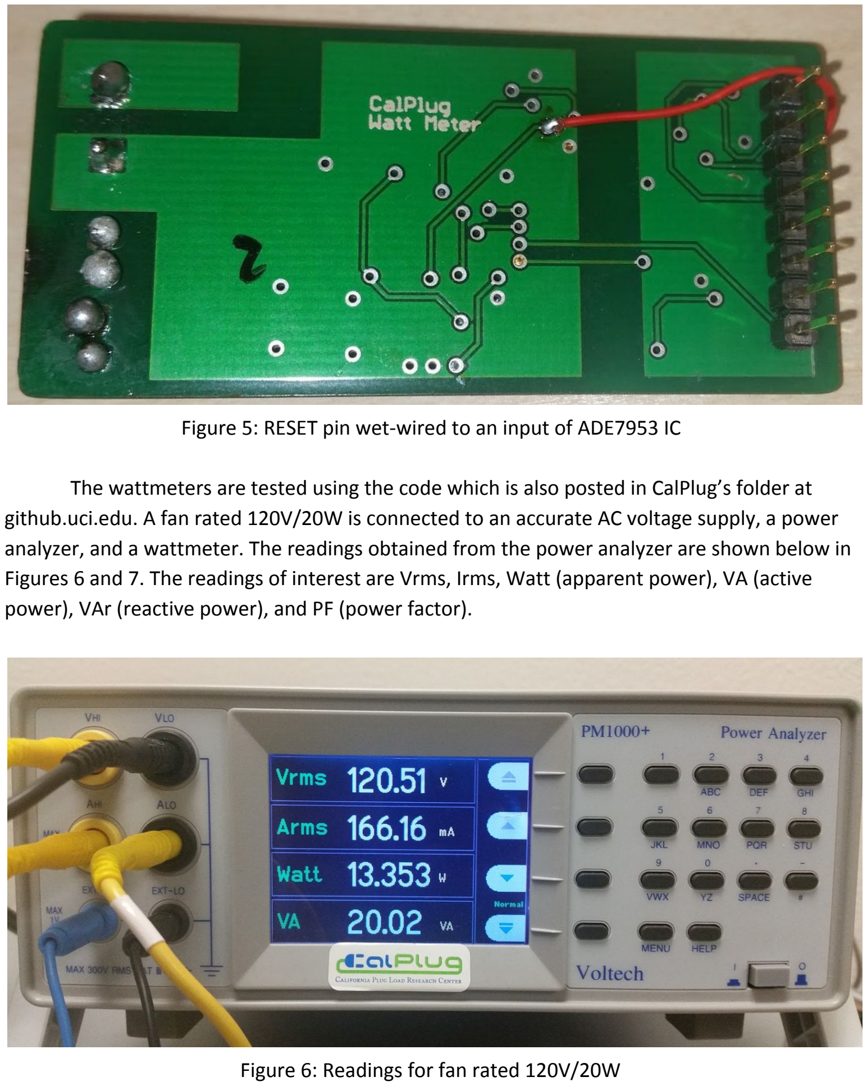
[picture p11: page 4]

Figure 5: RESET pin wet-wired to an input of ADE7953 IC

The wattmeters are tested using the code which is also posted in CalPlug’s folder at github.uci.edu. A fan rated 120V/20W is connected to an accurate AC voltage supply, a power analyzer, and a wattmeter. The readings obtained from the power analyzer are shown below in Figures 6 and 7. The readings of interest are Vrms, Irms, Watt (apparent power), VA (active power), VAr (reactive power), and PF (power factor).

Figure 6: Readings for fan rated 120V/20W

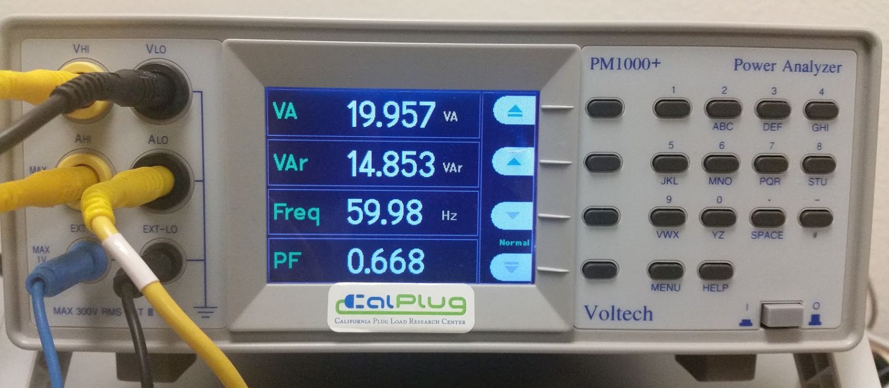
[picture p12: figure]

Figure 7: Readings for fan rated 120V/20W

The wattmeters are connected to an Atmel microcontroller board and the readings are obtained from the Serial Monitor. When nothing is connected to the microcontroller board’s SPI lines, the readings obtained are shown below in Figure 8. When a wattmeter with bad connections is connected to the SPI lines, the readings in Figure 9 are obtained. A working wattmeter gives the readings shown in Figure 10, which are very close to the power analyzer readings shown in Figures 6 and 7. As of now only current channel A of the wattmeters have been configured. Current channel B has not been configured.

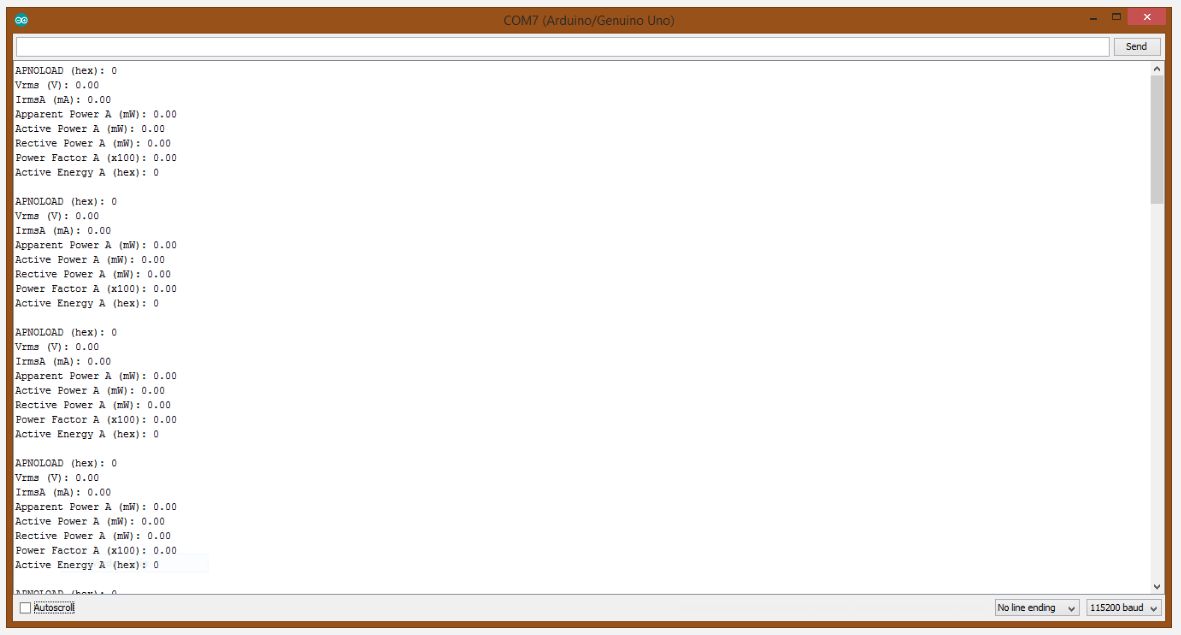
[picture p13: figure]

Figure 8: Readings for no wattmeter connected to microcontroller board

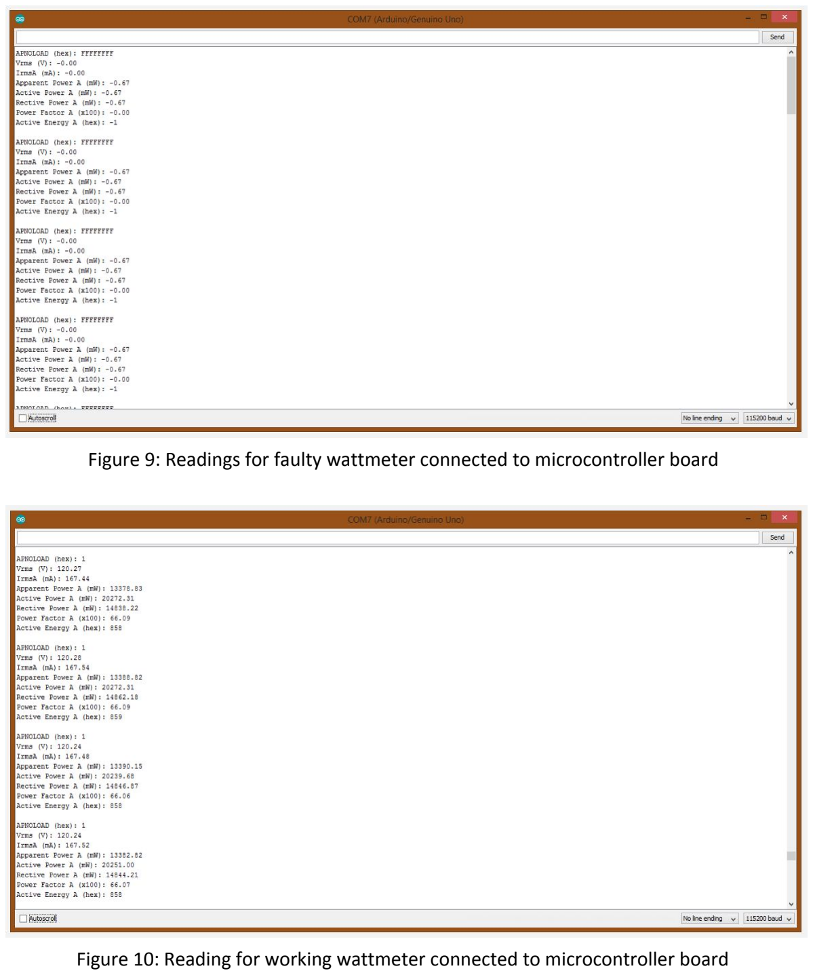
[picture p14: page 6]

Figure 9: Readings for faulty wattmeter connected to microcontroller board

Figure 10: Reading for working wattmeter connected to microcontroller board

Conclusion

Ten Calplug Wattmeters have been made and tested successfully using the methods described in this report. As of now, many of the functionalities offered by the ADE7953 have not been used. For future work, current channel B can be configured, and the library that has been created can be edited to unlock the other functionalities offered by the IC. Also, if PCBs for the wattmeters are reordered, the design will be revised to fit the isolator, so that stilting and wet-wiring would no longer be necessary.

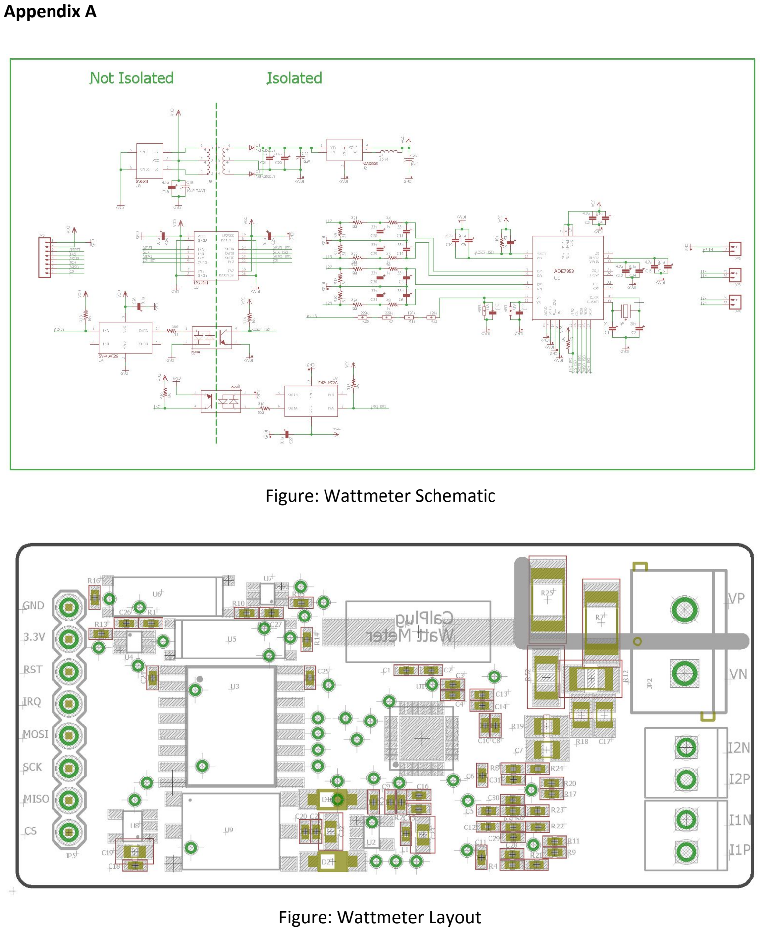
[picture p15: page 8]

Appendix A

Figure: Wattmeter Schematic

Figure: Wattmeter Layout

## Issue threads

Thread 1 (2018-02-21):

magic numbers

nampuapx, 2018-02-21:
This code for 60Hz....
 You are count all channels 1 sec...

File: ADE7953.cpp
On line 264:
```
float ADE7953::getIrmsA(){
	unsigned long value=0;
	value=spiAlgorithm32_read((functionBitVal(IRMSA_32,1)),(functionBitVal(IRMSA_32,0)));
	float decimal = decimalize(value, 1327, 0);
return decimal;
```
Why 1327?

On line 251:
```
float ADE7953::getVrms(){
	unsigned long value=0;
	value=spiAlgorithm32_read((functionBitVal(VRMS_32,1)),(functionBitVal(VRMS_32,0)));
	float decimal = decimalize(value, 19090, 0);
return decimal;
}
```
Why 19090?
Are these values were obtained by fitting?
Then why the values differ in dozens of times?
Thanks

mjklopfer, 2018-05-03:
Updates added to the code to clarify what the role of these values.  You may need to change them based on differences in resistors or chip batches in your design.  I flagged all the lines where calibration was used.
~Mike

miroslavpetrov, 2021-08-11:
I am trying to use your code for ADE7953 but as @nampuapx I am also having trouble understanding how the numbers used in the decimalize function are derived. I have looked at the excel table but unfortunately I cannot see there values even close to the ones used in the decimalize function.

I am using a 1 milliohm shunt resistor in my board and I am trying to get a reasonable current readings.

Closed 2018-05-03.

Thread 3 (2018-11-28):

strange readings

Gior80, 2018-11-28:
Hello!
I'm using your library to connect an ade7953 to an eps32.

I got this strange reading and I cannot figure out if I'm facing a communication problem

I'm using pin 13 for CS on the chip. FFFFFFFF is  -1  on AP_NOLOAD registry. this indicate some problems ?   I can't figure out reading datasheet as this value should be 1 or 0

APNOLOAD (hex): FFFFFFFF
Vrms (V): -1.00
IrmsA (mA): -0.00
Apparent Power A (mW): 0.67
Active Power A (mW): 0.67
Rective Power A (mW): -0.67
Power Factor A (x100): 0.00
Active Energy A (hex): -1

mjklopfer, 2018-12-10:
Arduino pin 13 is typically the clock for the Arduino Uno board for SPI  (https://www.arduino.cc/en/Reference/SPI and https://playground.arduino.cc/Code/Spi).  Check pins to make sure things are OK.  You can also try to scope it and make sure you are getting returns.  There is an SPI version for the Arduino Uno/ESP8266 and then a different version for the ESP32, as well as an Arduino Uno, tested I2C version posted.  All are tested as functional in most current posted version.

Gior80, 2018-12-11:
Thanks,

I read the guide and it give me nice information.  looking at picture number 9.  looks I have a faulty wattmeter.

just some question cause u probably have this problem before me:

1) how u determine the IC is faulty?
2) how, during assembly u damage the component ?
3) with ic off is there a certain way to verify component is ok? (ex. ground check on +/- pin)

Thanks!

Gior80, 2018-12-11:
think I found the problem.   I'm using GPIO14 ( sorry for the error ) as CS pin.

I see in example there's local_SS variable defined a 14,  so same as mine for test.

what is happening:   if,  after the loading and Ade  initialisation ,   you print out SCK,MOSI,MISO,CS ( doing it in loop)

void loop() {
  Serial.println(MOSI);
  Serial.println(MISO);
  Serial.println(SCK);
  Serial.println(SS);

what I got in answer is :

23
19
18
5  <<<<<<<<<<<<it shouldn't be 14???

APNOLOAD (hex): FFFFFFFF
Vrms (V): -0.00
IrmsA (mA): -0.00
Apparent Power A (mW): 0.67
Active Power A (mW): 0.67
Rective Power A (mW): -0.67
Power Factor A (x100): 0.00
Active Energy A (hex): -1

mjklopfer, 2018-12-11:
The SS pin on SPI is just a GPIO that triggers the IC to become active on LOW (for the ADE7953),  Whatever it is defined as, use, or redefine to whatever pin you are using.  It is not part of the Arduino Uno's "Hardware SPI" pins.

You really need to use an oscilloscope or logic analyzer to see what is going on for troubleshooting.  Otherwise you are using an advanced guess and check method.

Gior80, 2018-12-11:
I just buy an oscilloscope cause you are right in this sense.  no way to test spi communication without and no way to understand the problem with no sure measurements
gonna make tests and then see results.
About reset_iso pin instead ,  could you explain me more about hoe it work?  it is always "high" except for resetting the Ade at beginning ?

Gior80, 2018-12-11:
can be closed .  that was an absolutely stupid wiring error 👍 . damn!!!!
thanks for your time :)

mjklopfer, 2018-12-11:
Beyond the SPI pins on the boards (assuming the SPI version) there is an optically isolated RESET pin and an optically isolated Interrupt request (IRQ).  In the V4 board there is also a SELECT input.

The RESET is an input.  We inverted the reset pin so the board's user wouldn't need to pull it high to make the ADE7953 operate.  Unless you plan to reset the ADE7953 in operation, you can leave unconnected.

The IRQ pin is an isolated output.  Unless you are using the using the IRQ features of the ADE7953 (say to trigger a flag above a specific accumulated load or timed waveform sampling), you can leave that pin unconnected.

The SELECT input allows you to sample from one of two possible voltage channel inputs sequentially.  This can be used with single-phase inputs for ground fault detection, unpolarized plugs (ambiguous input for line vs. neutral), or measurement of split-phase (2 phase) AC sources such as 240VAC supplies.

Good luck with your project!

jeykayaem, 2021-03-17:
hi,getting the same error

Closed 2018-12-10.

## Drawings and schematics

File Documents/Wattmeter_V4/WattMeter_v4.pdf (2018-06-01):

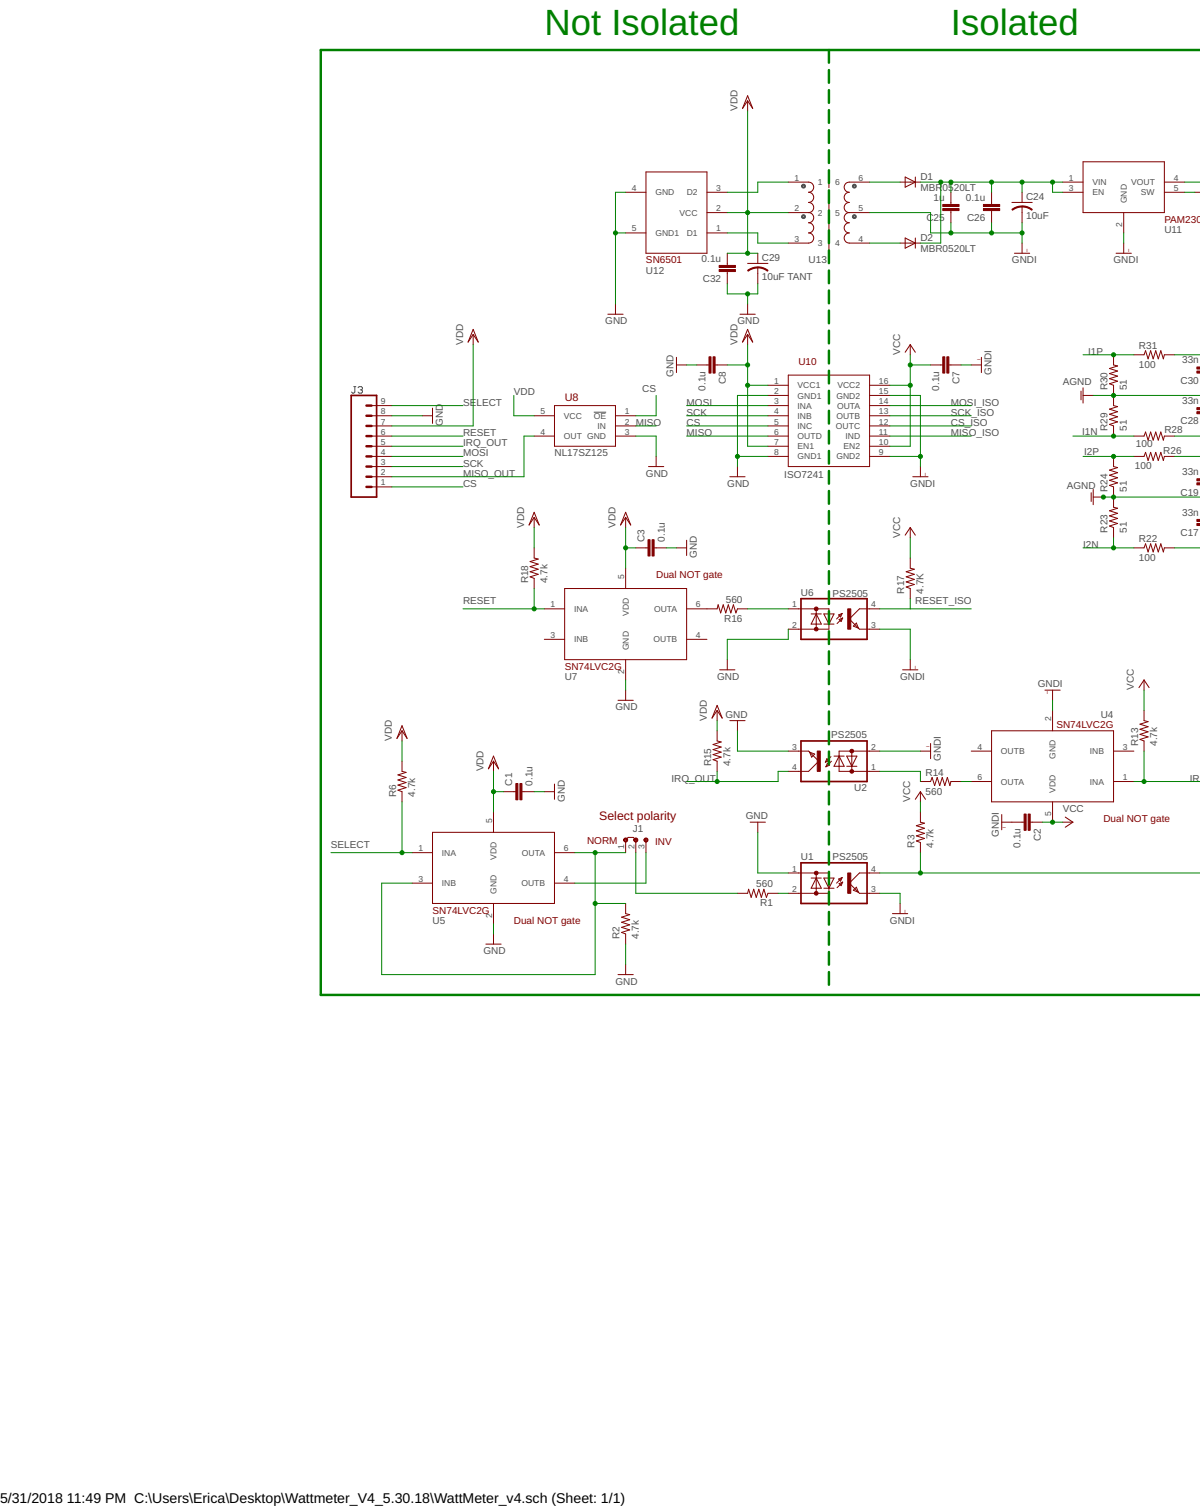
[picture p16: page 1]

5/31/2018 11:49 PM C:\Users\Erica\Desktop\Wattmeter_V4_5.30.18\WattMeter_v4.sch (Sheet: 1/1)

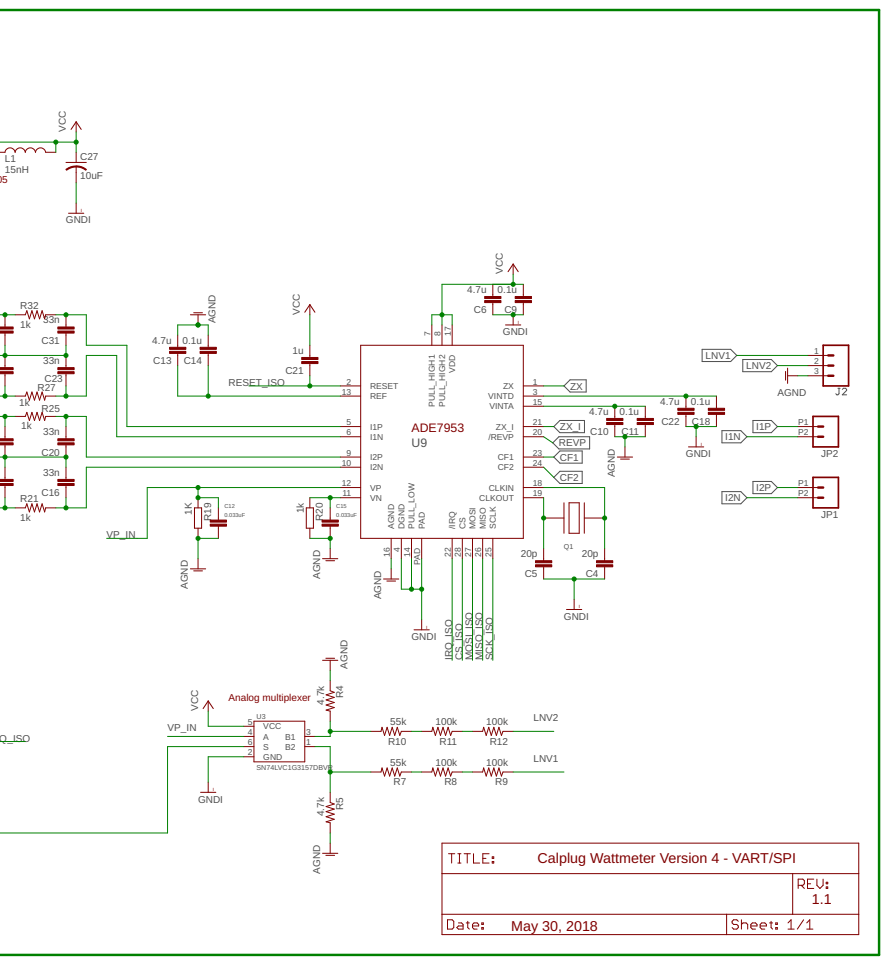
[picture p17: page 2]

Calplug Wattmeter Version 4 - VART/SPI

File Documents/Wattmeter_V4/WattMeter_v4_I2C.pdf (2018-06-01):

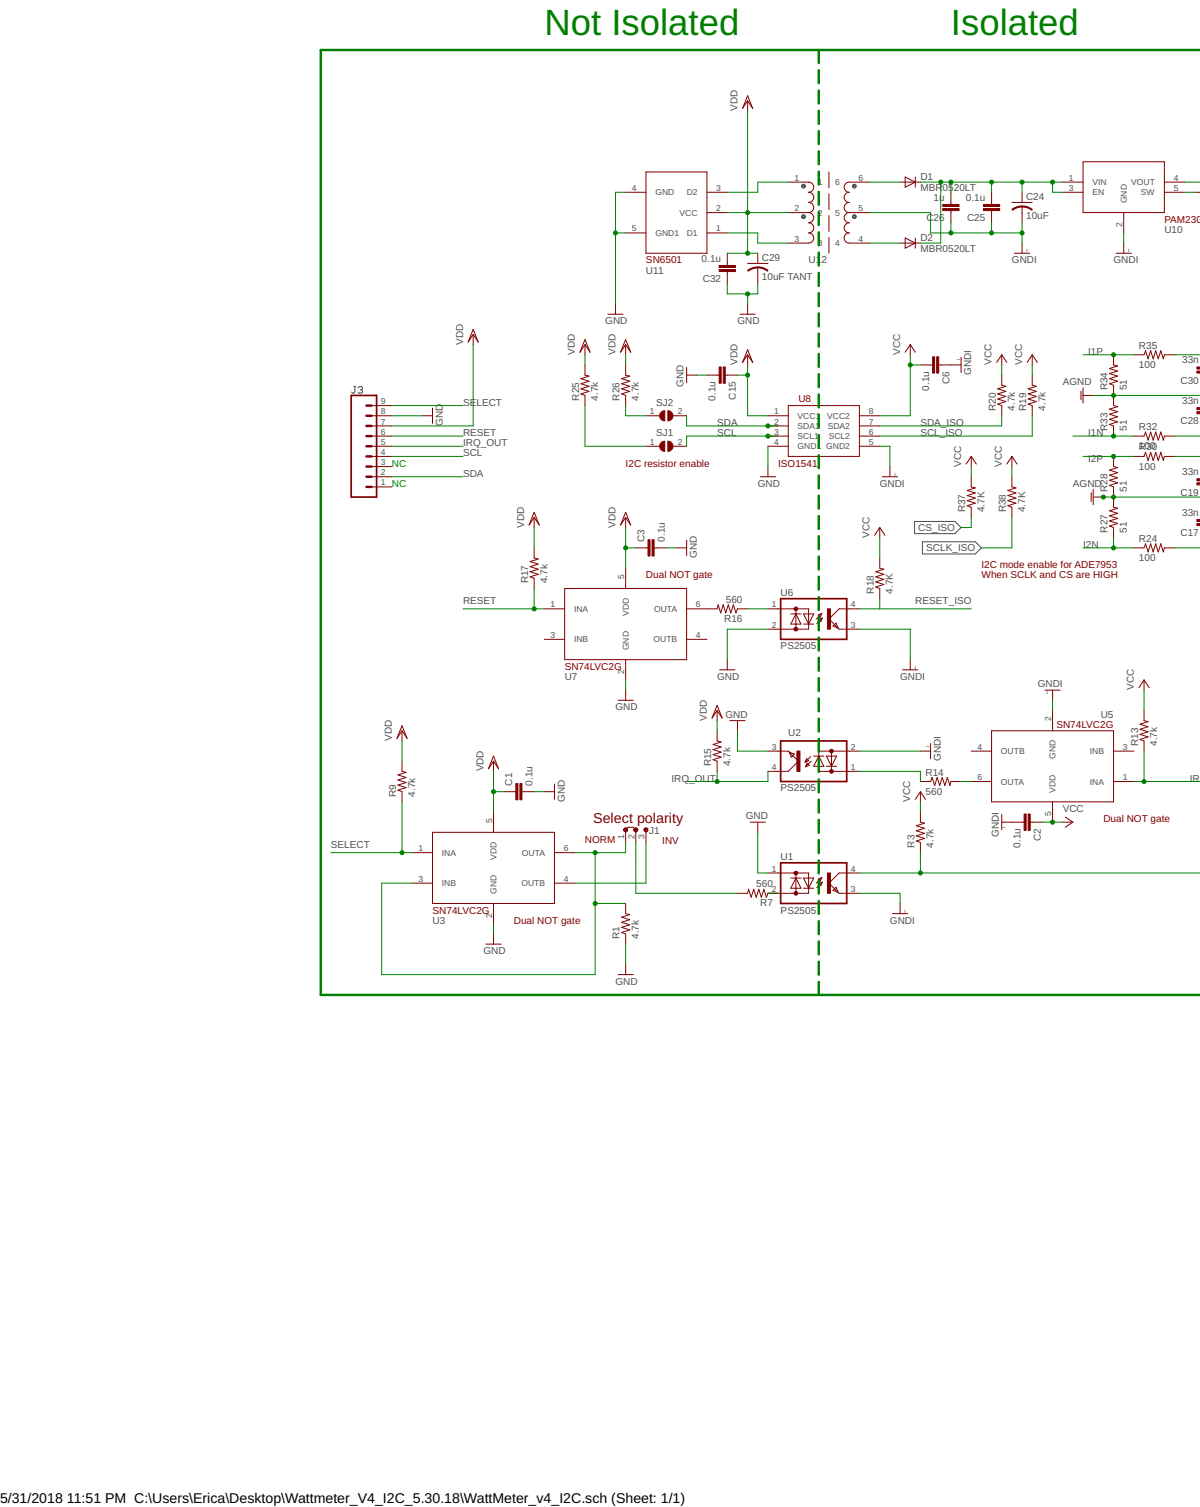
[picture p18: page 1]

I2C mode enable for ADE7953
When SCLK and CS are HIGH

5/31/2018 11:51 PM C:\Users\Erica\Desktop\Wattmeter_V4_I2C_5.30.18\WattMeter_v4_I2C.sch (Sheet: 1/1)

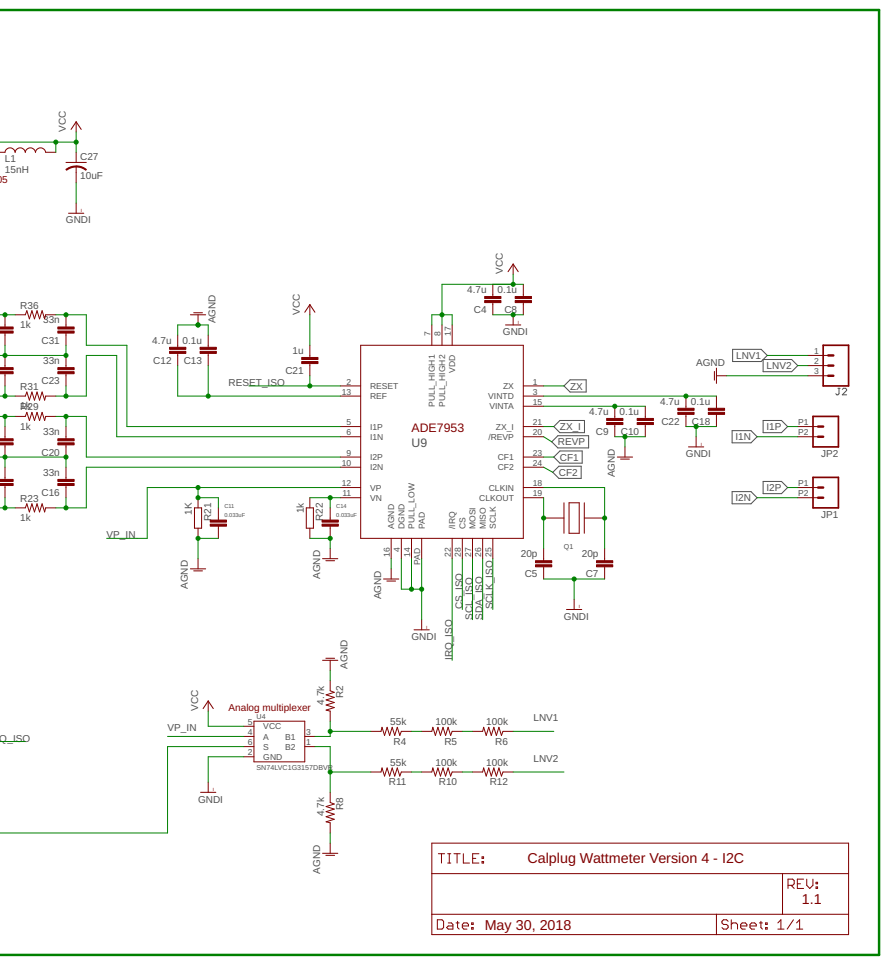
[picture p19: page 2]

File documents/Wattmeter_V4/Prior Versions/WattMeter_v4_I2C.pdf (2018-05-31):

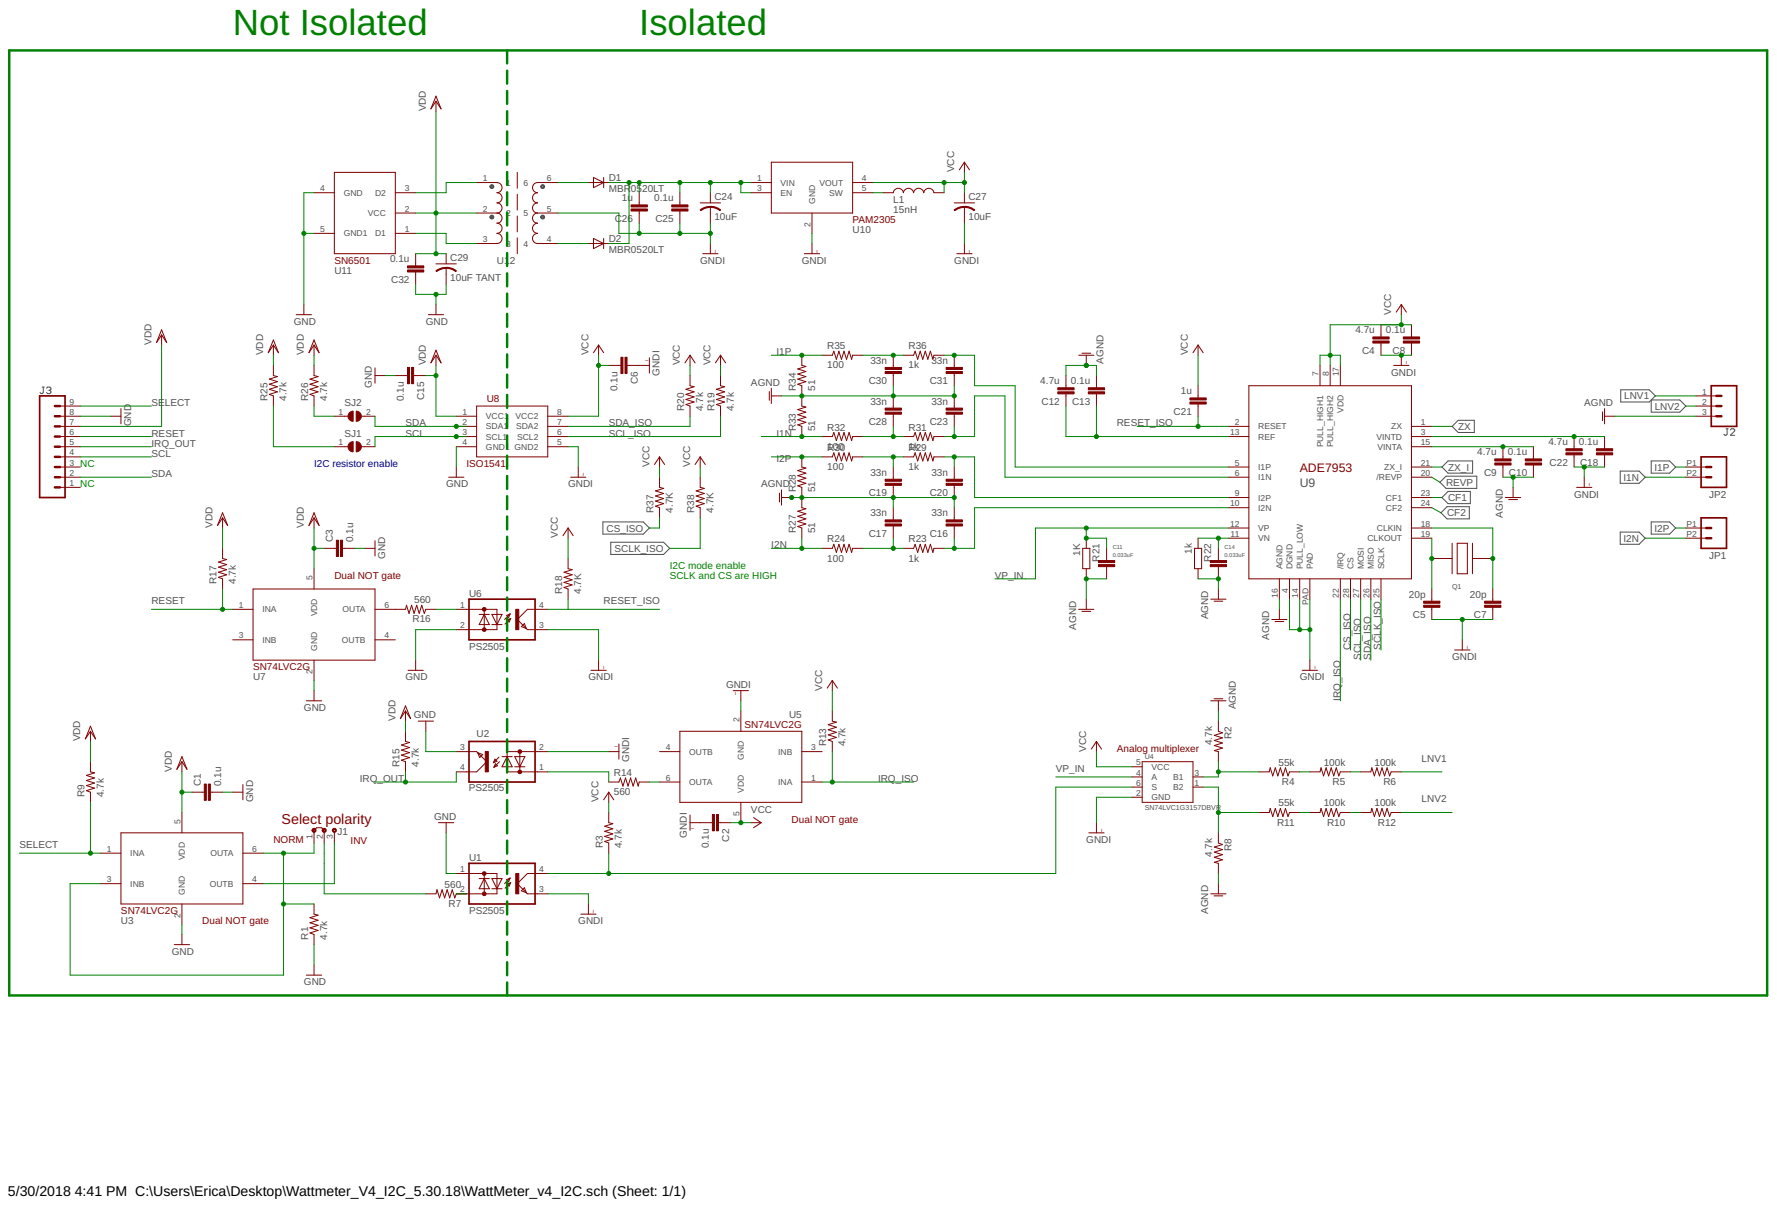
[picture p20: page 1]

I2C mode enable SCLK and CS are HIGH

5/30/2018 4:41 PM C:\Users\Erica\Desktop\Wattmeter_V4_I2C_5.30.18\WattMeter_v4_I2C.sch (Sheet: 1/1)

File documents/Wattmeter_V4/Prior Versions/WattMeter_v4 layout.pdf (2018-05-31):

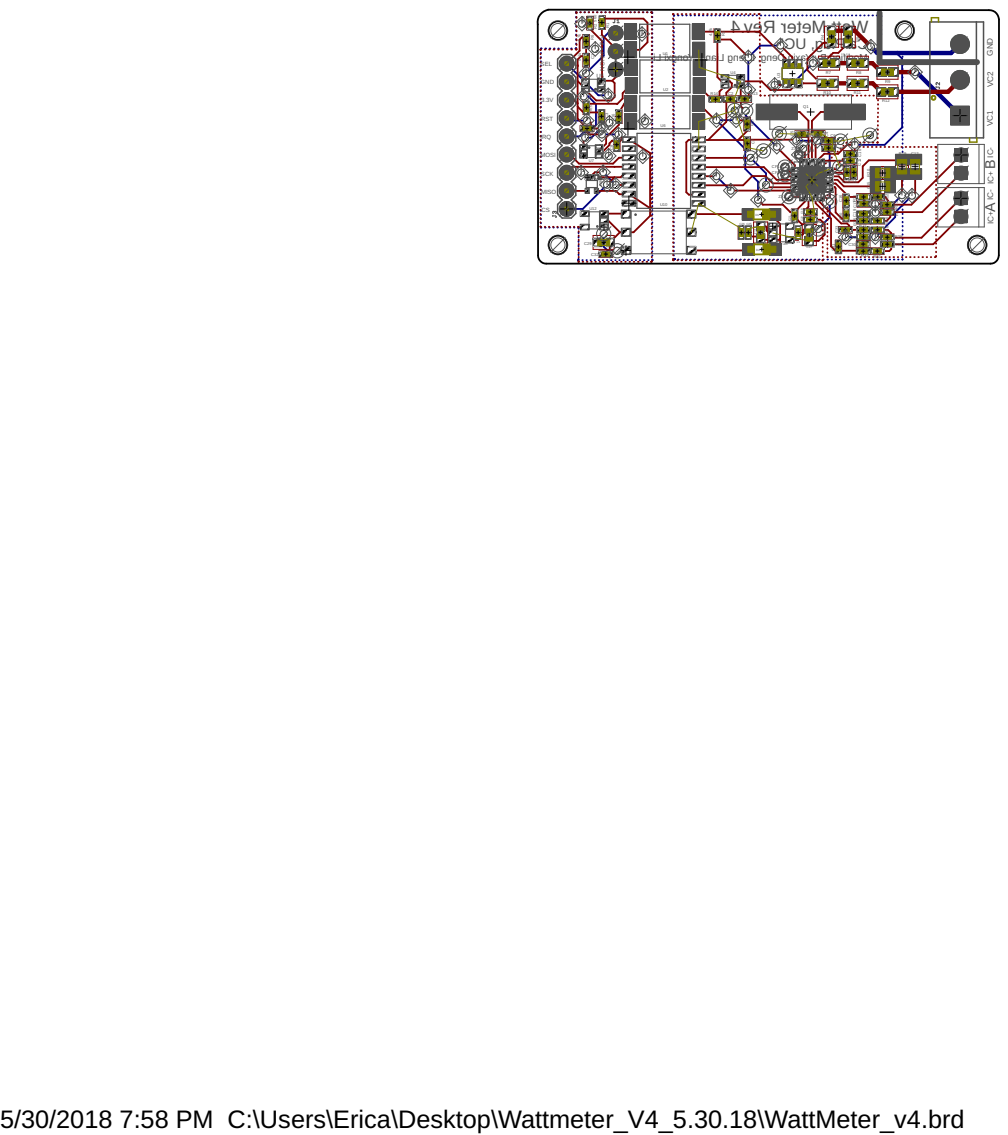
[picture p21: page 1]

IRQ MOSI SCK MISO

5/30/2018 7:58 PM C:\Users\Erica\Desktop\Wattmeter_V4_5.30.18\WattMeter_v4.brd

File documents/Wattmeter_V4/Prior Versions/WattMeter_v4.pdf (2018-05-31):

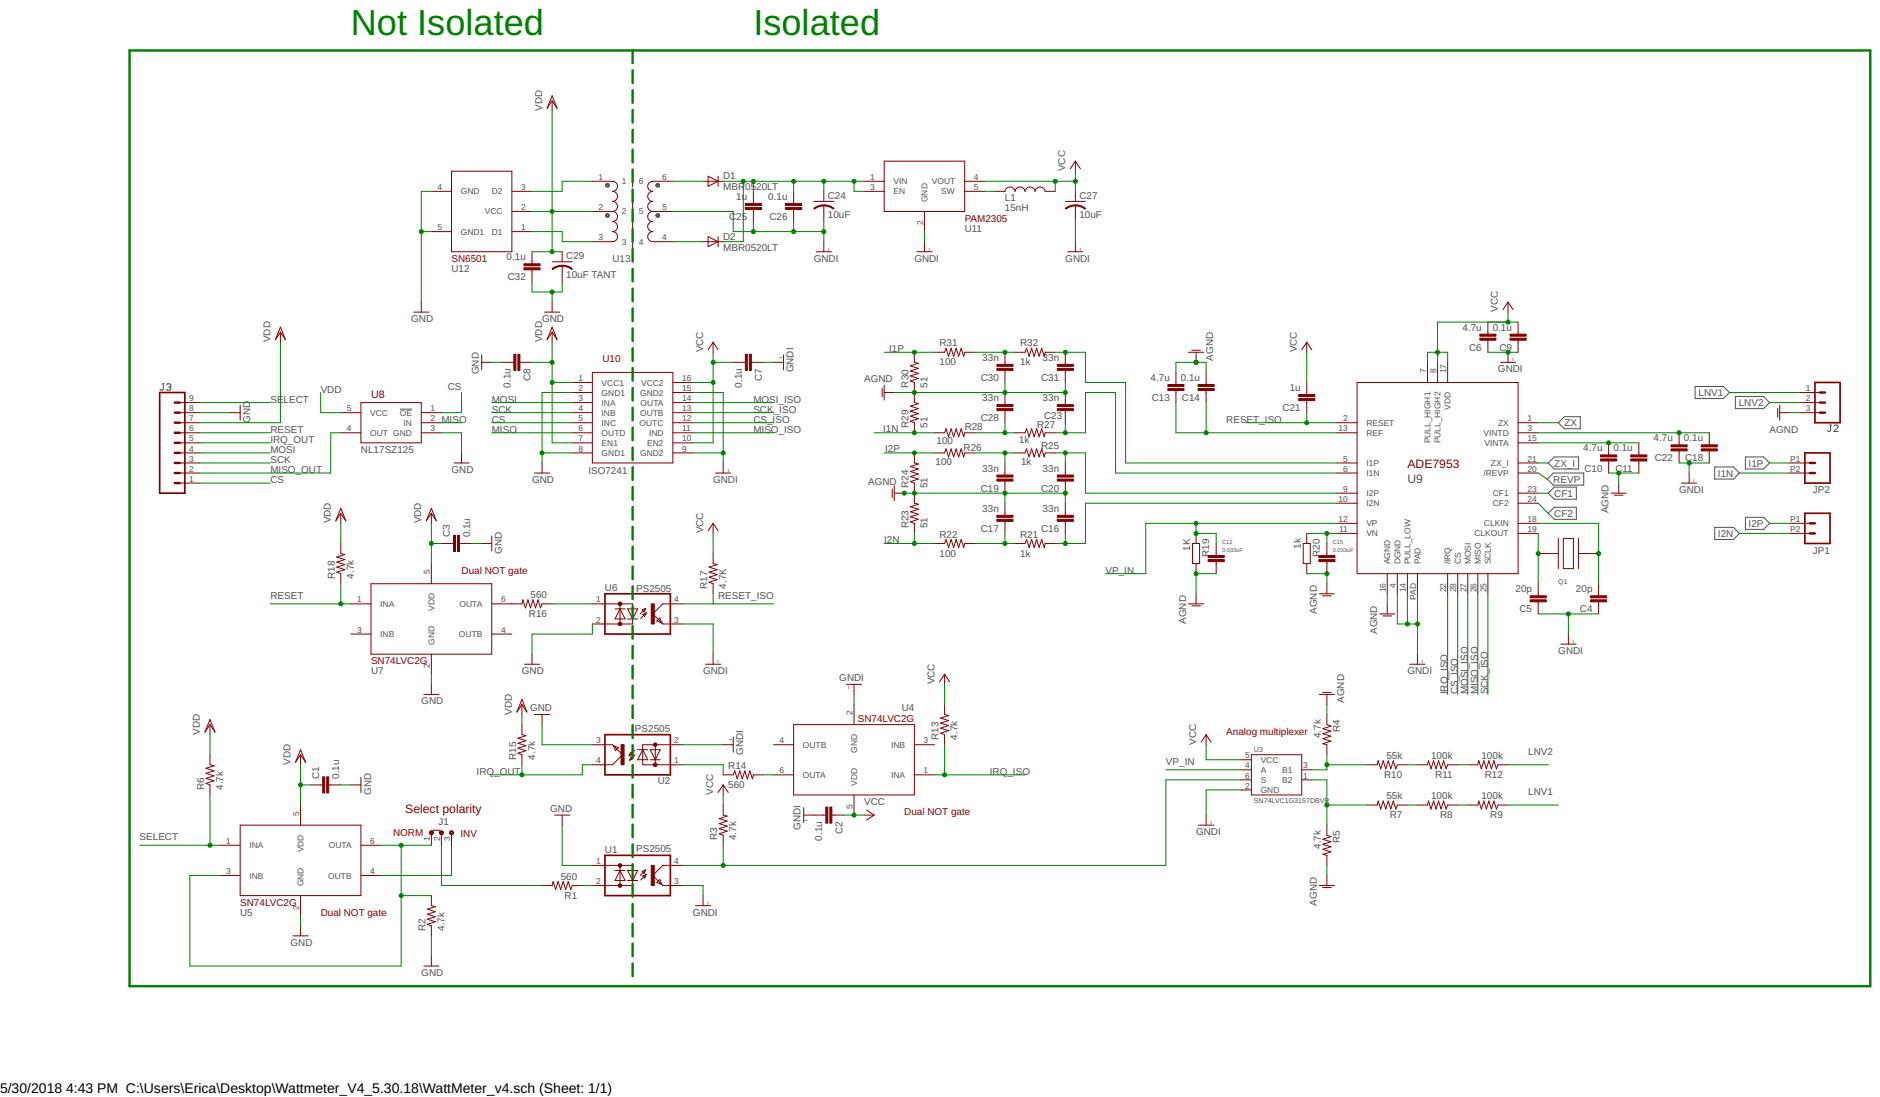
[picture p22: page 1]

5/30/2018 4:43 PM C:\Users\Erica\Desktop\Wattmeter_V4_5.30.18\WattMeter_v4.sch (Sheet: 1/1)

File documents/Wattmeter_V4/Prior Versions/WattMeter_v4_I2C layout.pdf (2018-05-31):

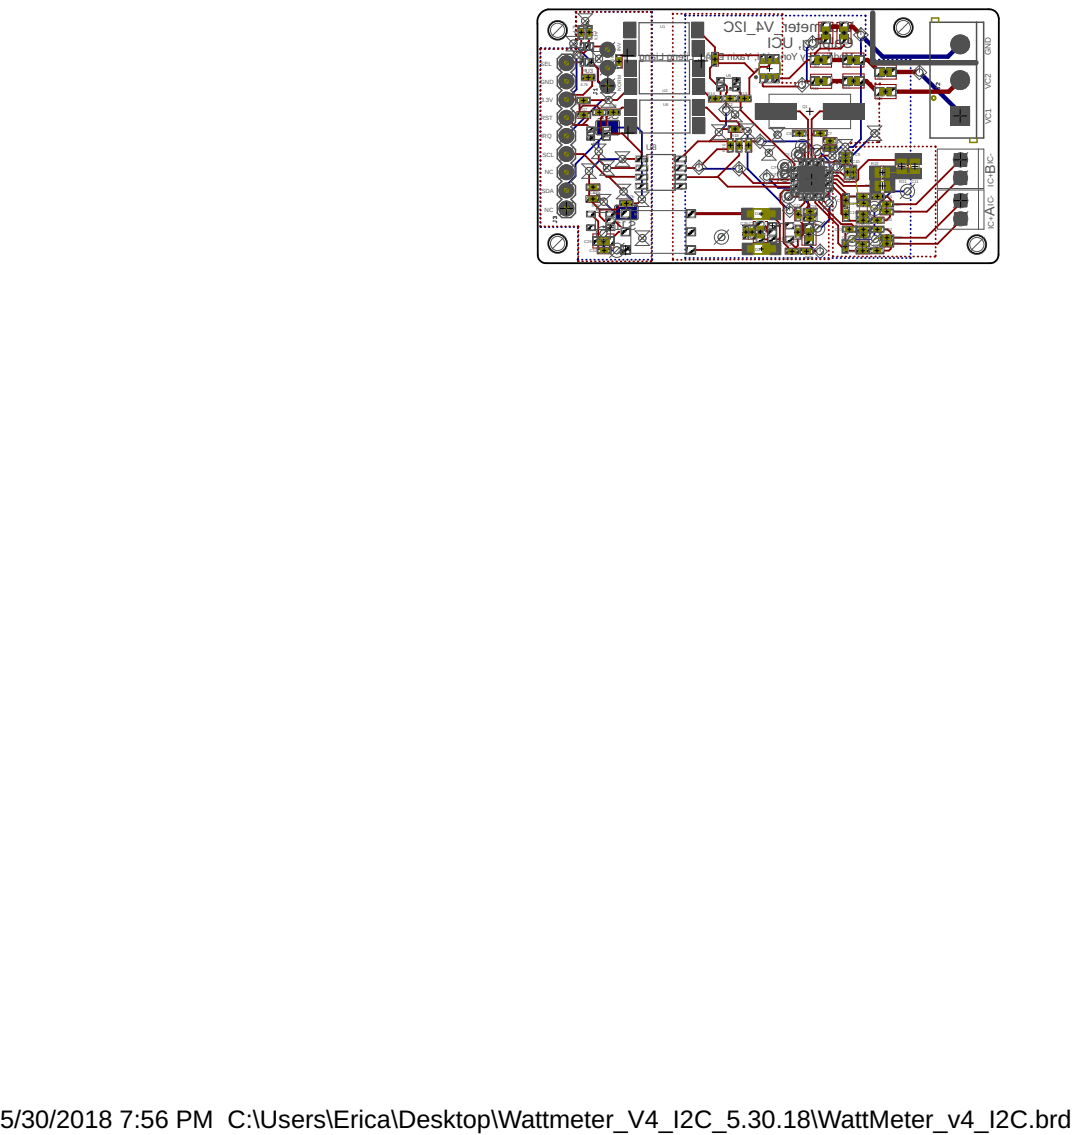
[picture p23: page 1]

5/30/2018 7:56 PM C:\Users\Erica\Desktop\Wattmeter_V4_I2C_5.30.18\WattMeter_v4_I2C.brd

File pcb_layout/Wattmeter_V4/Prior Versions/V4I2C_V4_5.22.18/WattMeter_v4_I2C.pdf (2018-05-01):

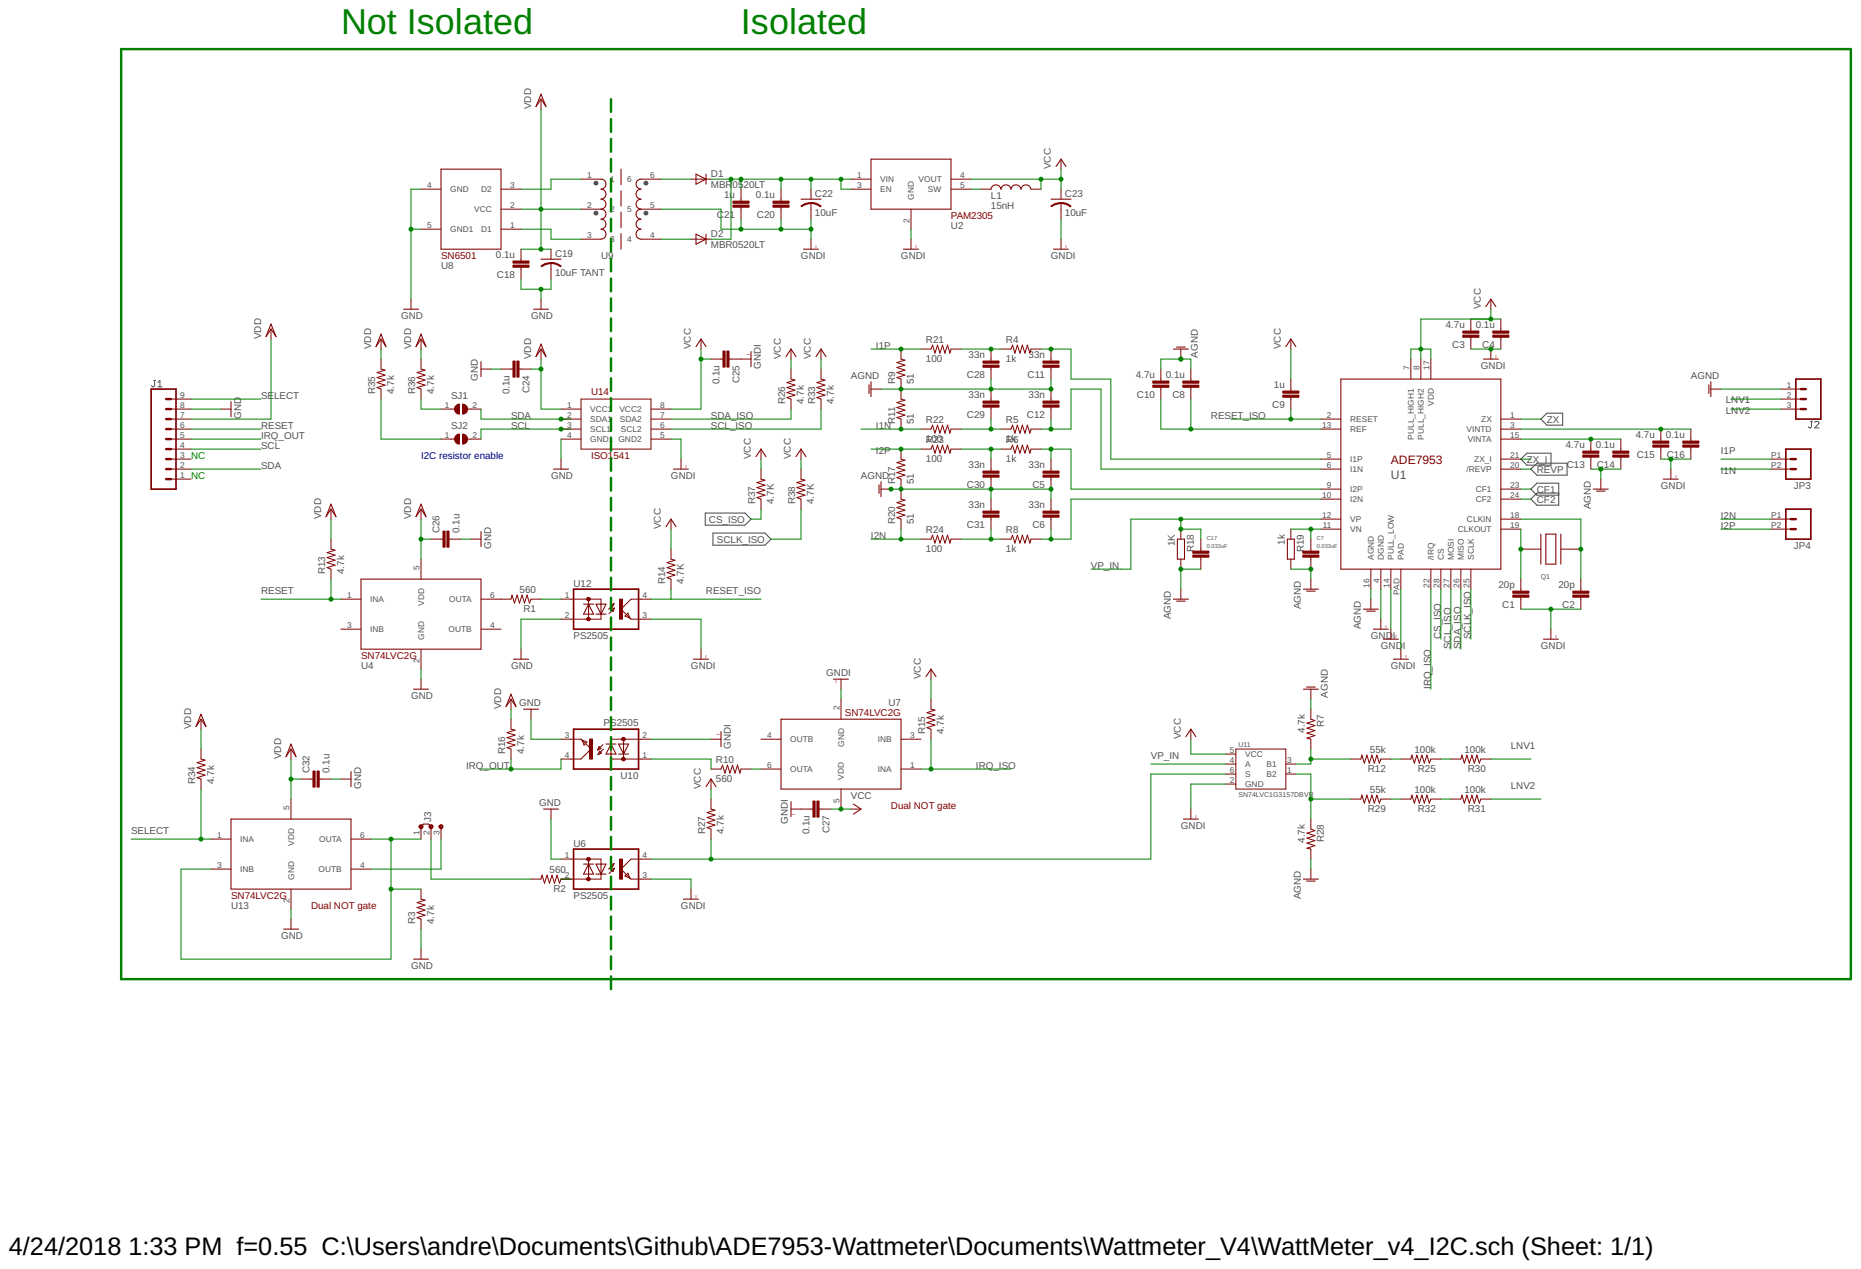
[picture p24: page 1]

4/24/2018 1:33 PM f=0.55 C:\Users\andre\Documents\Github\ADE7953-Wattmeter\Documents\Wattmeter_V4\WattMeter_v4_I2C.sch (Sheet: 1/1)

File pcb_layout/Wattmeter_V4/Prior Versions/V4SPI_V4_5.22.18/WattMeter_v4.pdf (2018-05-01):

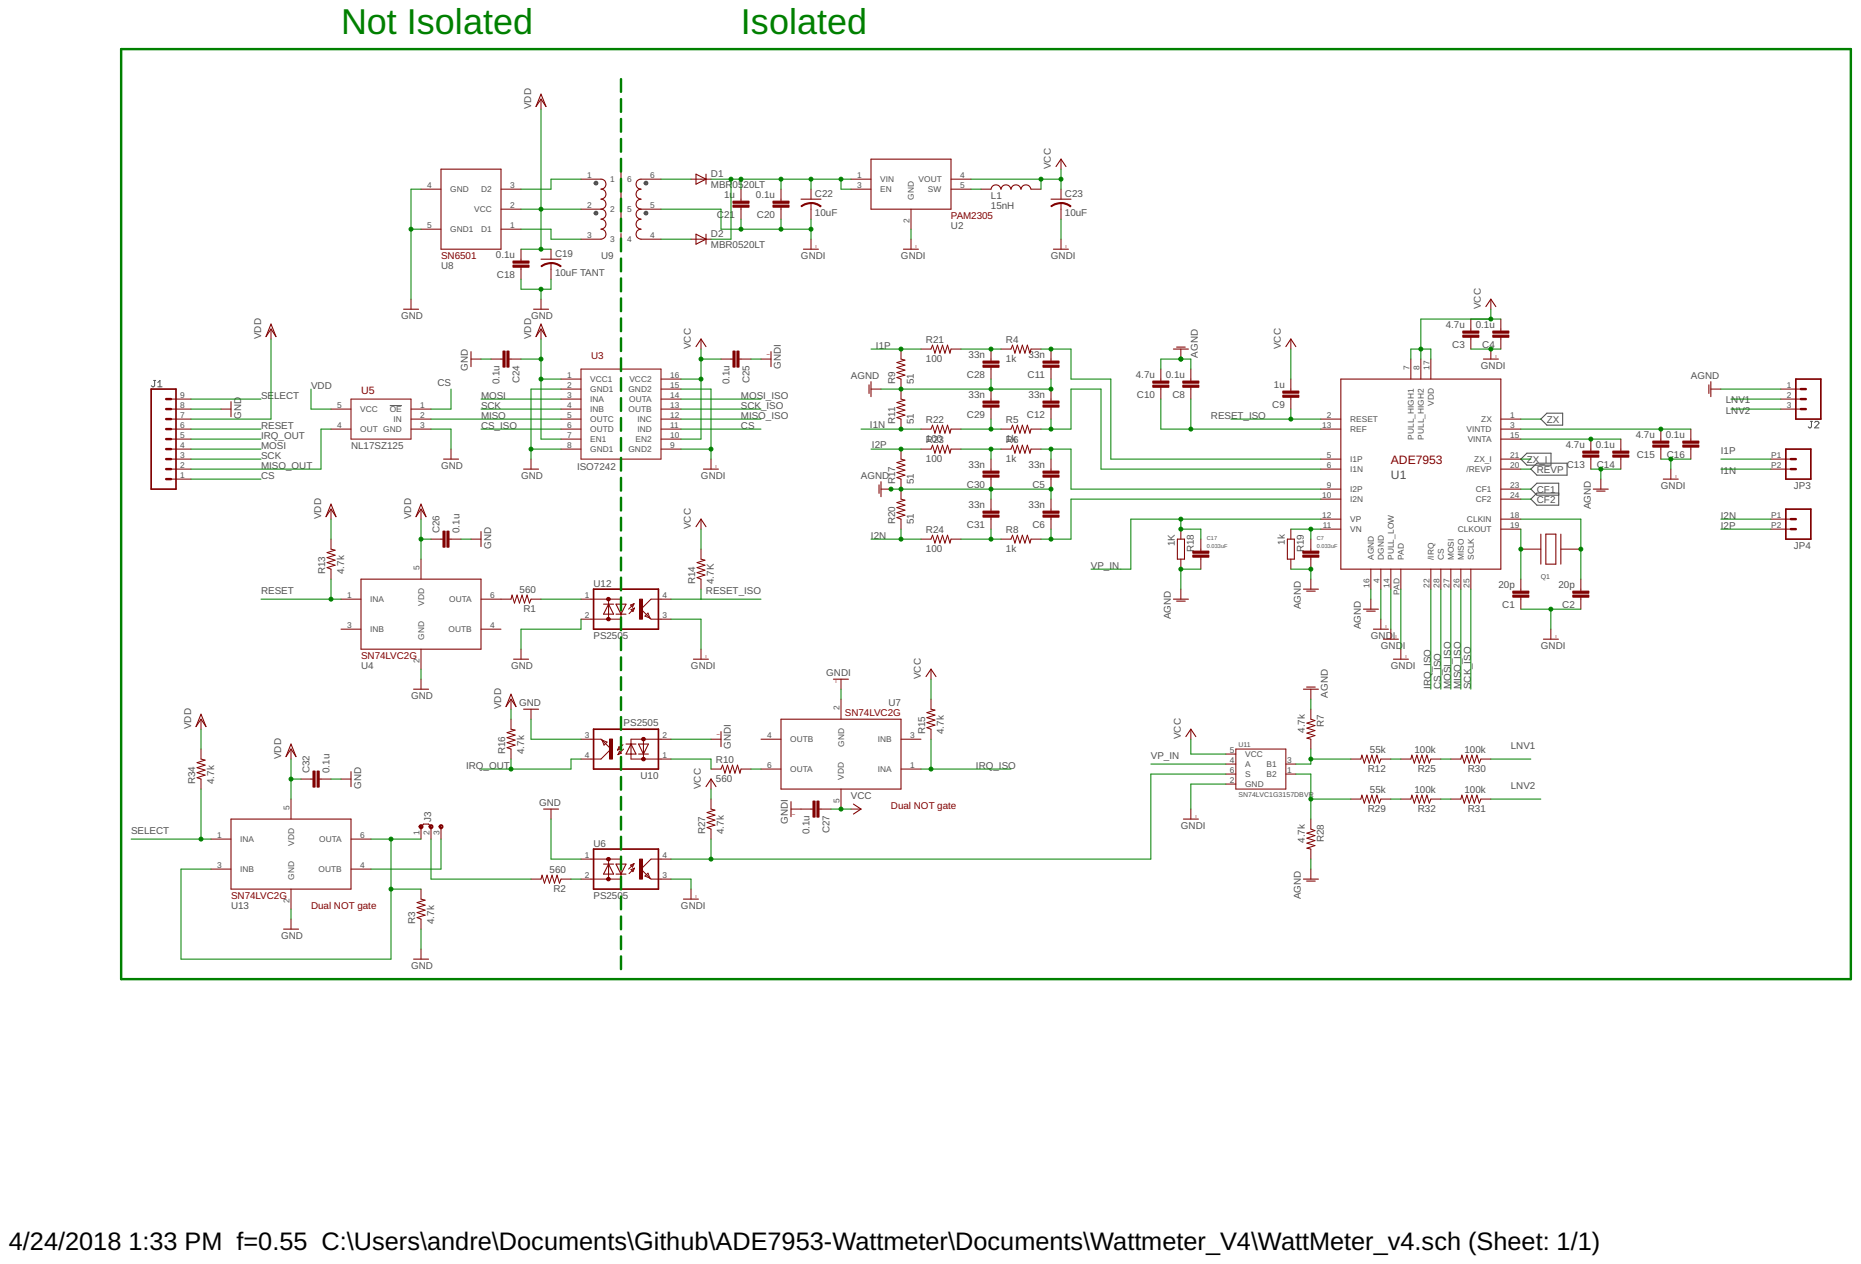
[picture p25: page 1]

4/24/2018 1:33 PM f=0.55 C:\Users\andre\Documents\Github\ADE7953-Wattmeter\Documents\Wattmeter_V4\WattMeter_v4.sch (Sheet: 1/1)

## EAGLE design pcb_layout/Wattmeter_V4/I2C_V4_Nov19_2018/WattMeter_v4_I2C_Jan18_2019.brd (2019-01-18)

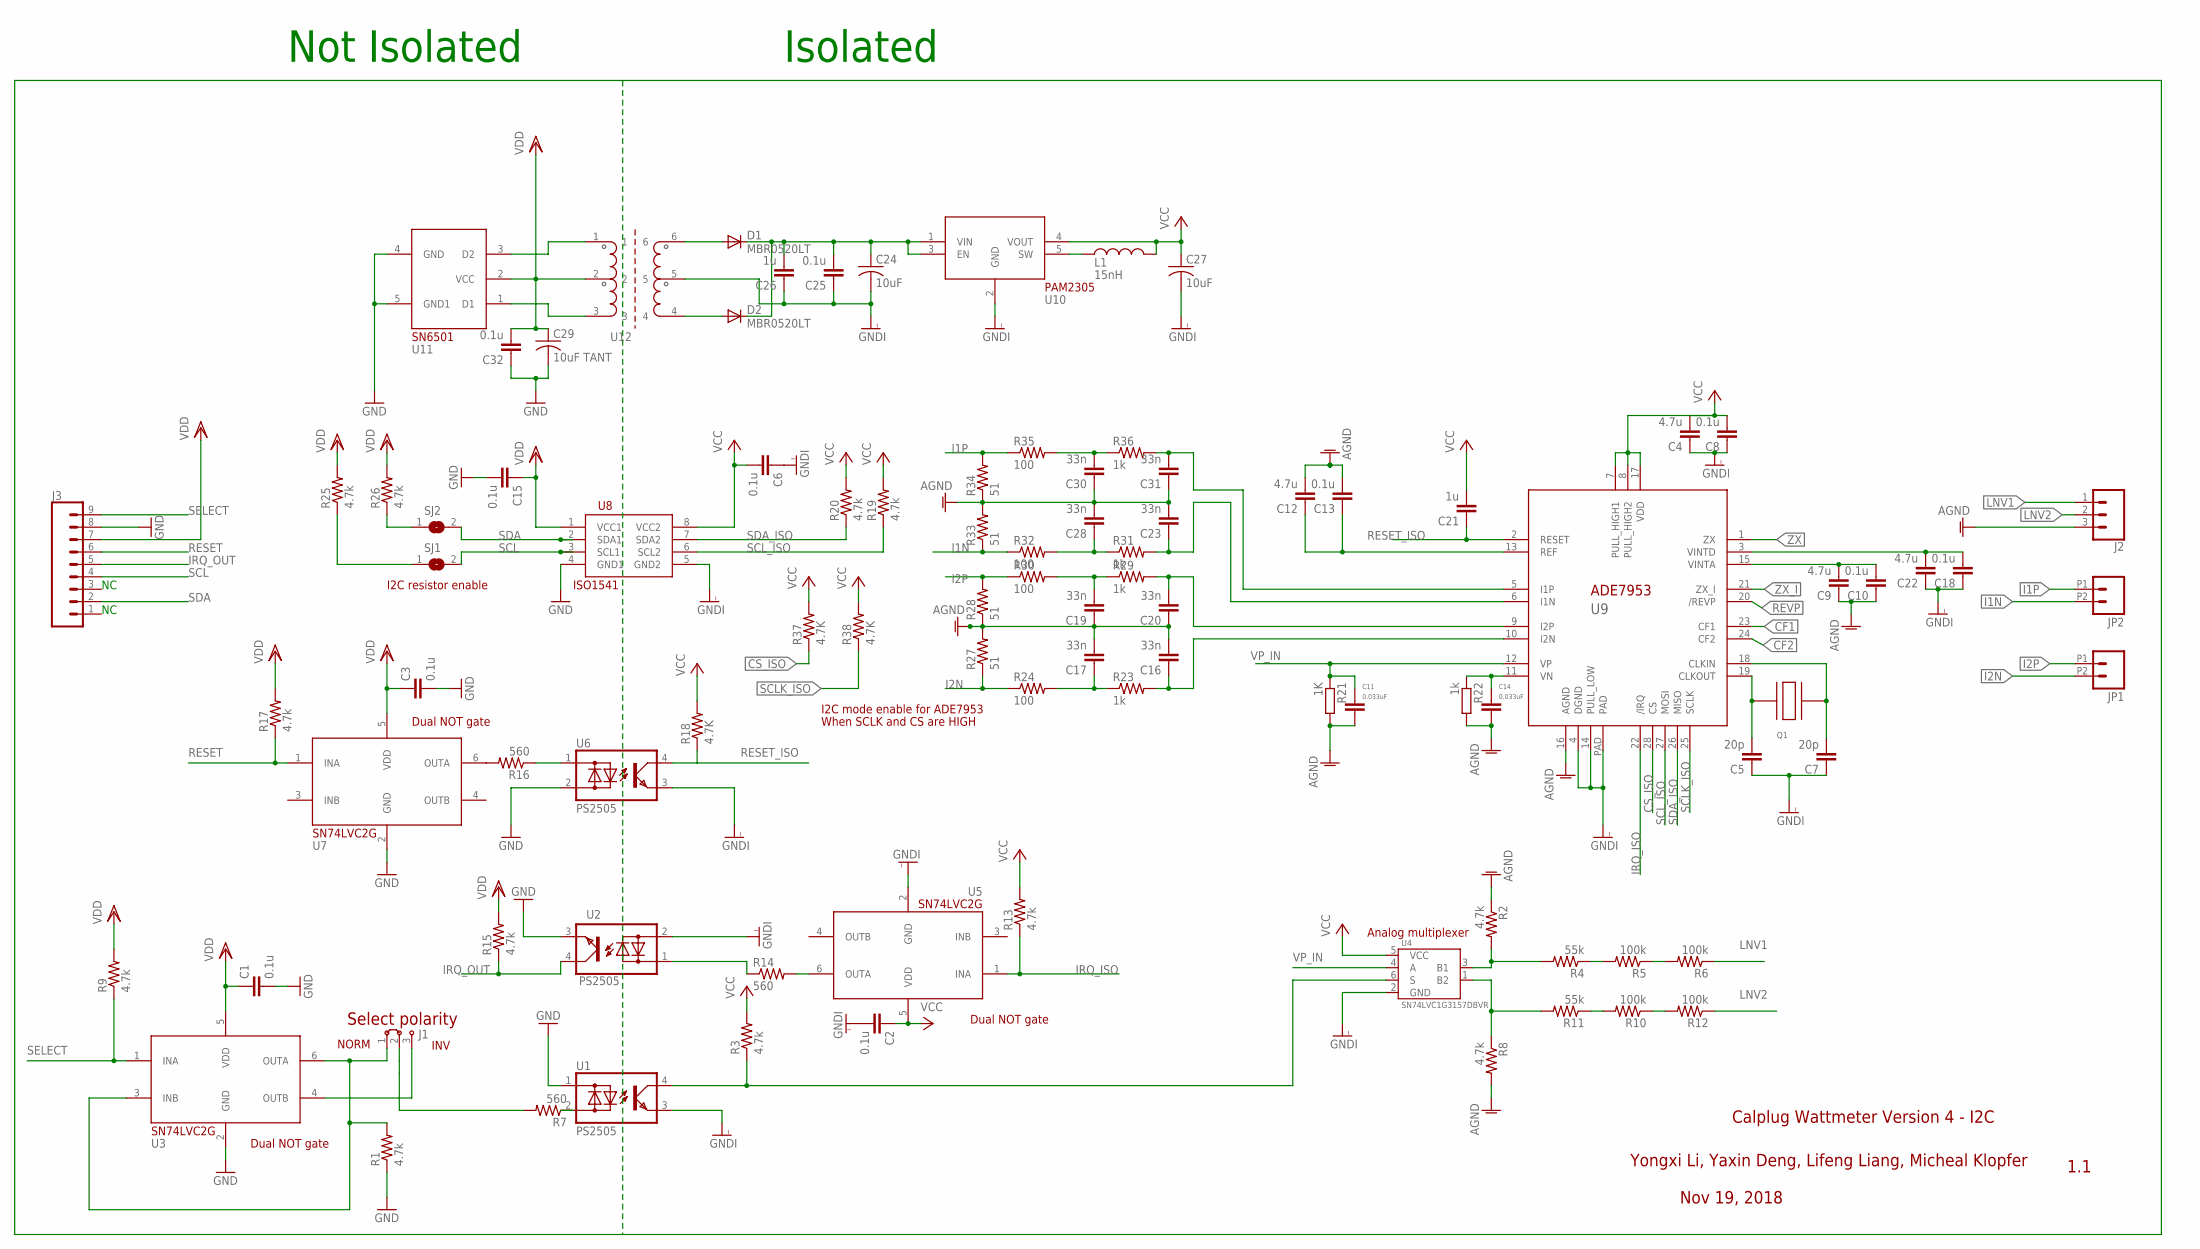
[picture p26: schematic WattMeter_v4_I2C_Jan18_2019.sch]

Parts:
C1, C2, C3, C6, C8, C10, C13, C15, C18, C25, C32: 0.1u; 0402-CAP
C4, C9, C12, C22: 4.7u; 0402-CAP
C5, C7: 20p; 0402-CAP
C11, C14: 0.033uF; C0805K
C16, C17, C19, C20, C23, C28, C30, C31: 33n; 0402-CAP
C21, C26: 1u; 0402-CAP
C24, C27: 10uF; C0603
C29: 10uF TANT; C0603
D1, D2: MBR0520LT; SOD123
J1: JUMPER3; 1X03
J2: CONN_03-SCREW-5MM; SCREWTERMINAL-5MM-3
J3: CONN_09; 1X09
JP1, JP2: M022.54MM_SCREWTERM; 1X02_2.54_SCREWTERM
L1: 15nH; 0402-RES
Q1: QUARTZ_3.58M_2PIN; HC-49S
R1, R3, R9, R13, R15, R17, R19, R20, R25, R26: 4.7k; 0402-RES
R2, R8: 4.7k; 0603-RES
R4, R11: 55k; 0603-RES
R5, R6, R10, R12: 100k; 0603-RES
R7, R14, R16: 560; 0402-RES
R18, R37, R38: 4.7K; 0402-RES
R21: 1K; C0805K@1
R22: 1k; C0805K@1
R23, R29, R31, R36: 1k; 0402-RES
R24, R30, R32, R35: 100; 0402-RES
R27, R28, R33, R34: 51; 0402-RES
SJ1, SJ2: SJ
U1, U2, U6: PS2505
U3, U5, U7: SN74LVC; DCKT
U4: SN74LVC1G3157DBVR; SOT-23-6
U8: ISO1541
U9: ADE7953; 28-WFQFN
U10: PAM2305; TSOT25
U11: SN6501; SOT-23-5
U12: TRANSFO_3.3

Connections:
AGND: C9.1, C10.1, C11.2, C12.2, C13.2, C14.2, C16.2, C17.2, C19.1, C20.1, C23.2, C28.2, C30.1, C31.1, J2.3, R2.1, R8.2, R21.2, R22.2, R27.2, R28.1, R33.2, R34.1, U9.16 (AGND)
CF1: U9.23 (CF1)
CF2: U9.24 (CF2)
CS_ISO: R37.1, U9.28 (CS)
GND: C1.2, C3.2, C15.2, C29.2, C32.1, J3.8, R1.1, U1.1 (ANODE), U2.3 (EMITTER), U3.2 (GND), U6.2 (CATHODE), U7.2 (GND), U8.4 (GND1), U11.4 (GND), U11.5 (GND1)
GNDI: C2.2, C4.1, C5.1, C6.1, C7.1, C8.1, C18.1, C22.1, C24.2, C25.1, C26.1, C27.2, U1.3 (EMITTER), U2.2 (CATHODE), U4.2 (GND), U5.2 (GND), U6.3 (EMITTER), U8.5 (GND2), U9.4 (DGND), U9.14 (PULL_LOW), U9.PAD, U10.2 (GND), U12.5
I1N: JP2.P2 (2), R32.1, R33.1
I1P: JP2.P1 (1), R34.2, R35.1
I2N: JP1.P2 (2), R24.1, R27.1
I2P: JP1.P1 (1), R28.2, R30.1
IRQ_ISO: R13.1, U5.1 (INA), U9.22 (/IRQ)
IRQ_OUT: J3.5, R15.1, U2.4 (COLLERTOR)
LNV1: J2.1, R6.1
LNV2: J2.2, R12.1
unnamed: C5.2, Q1.1, U9.19 (CLKOUT)
unnamed: C7.2, Q1.2, U9.18 (CLKIN)
unnamed: C14.1, R22.1, U9.11 (VN)
unnamed: L1.1, U10.5 (SW)
unnamed: C12.1, C13.1, U9.13 (REF)
unnamed: C9.2, C10.2, U9.15 (VINTA)
unnamed: C23.1, R31.2, U9.6 (I1N)
unnamed: C31.2, R36.2, U9.5 (I1P)
unnamed: C18.2, C22.2, U9.3 (VINTD)
unnamed: R10.1, R12.2
unnamed: J1.3, U3.4 (OUTB)
unnamed: D1.A, U12.6
unnamed: C24.1, C25.2, C26.2, D1.C, D2.C, U10.1 (VIN), U10.3 (EN)
unnamed: D2.A, U12.4
unnamed: U11.3 (D2), U12.1
unnamed: R10.2, R11.1
unnamed: U11.1 (D1), U12.3
unnamed: C30.2, R35.2, R36.1
unnamed: R16.1, U6.1 (ANODE)
unnamed: R16.2, U7.6 (OUTA)
unnamed: C28.1, R31.1, R32.2
unnamed: C16.1, R23.2, U9.10 (I2N)
unnamed: R26.1, SJ2.1
unnamed: R14.2, U5.6 (OUTA)
unnamed: C20.2, R29.2, U9.9 (I2P)
unnamed: C19.2, R29.1, R30.2
unnamed: C17.1, R23.1, R24.2
unnamed: R5.1, R6.2
unnamed: R4.1, R5.2
unnamed: R8.1, R11.2, U4.1 (B2)
unnamed: R2.2, R4.2, U4.3 (B1)
unnamed: R14.1, U2.1 (ANODE)
unnamed: J1.1, R1.2, U3.3 (INB), U3.6 (OUTA)
unnamed: J1.2, R7.2
unnamed: R7.1, U1.2 (CATHODE)
unnamed: R25.1, SJ1.1
RESET: J3.6, R17.1, U7.1 (INA)
RESET_ISO: C21.1, R18.1, U6.4 (COLLERTOR), U9.2 (RESET)
REVP: U9.20 (/REVP)
SCL: J3.4, SJ1.2, U8.3 (SCL1)
SCLK_ISO: R38.1, U9.25 (SCLK)
SCL_ISO: R19.1, U8.6 (SCL2), U9.27 (MOSI)
SDA: J3.2, SJ2.2, U8.2 (SDA1)
SDA_ISO: R20.1, U8.7 (SDA2), U9.26 (MISO)
SELECT: J3.9, R9.1, U3.1 (INA)
SETPHASE: R3.1, U1.4 (COLLERTOR), U4.6 (S)
VCC: C2.1, C4.2, C6.2, C8.2, C21.2, C27.1, L1.2, R3.2, R13.2, R18.2, R19.2, R20.2, R37.2, R38.2, U4.5 (VCC), U5.5 (VDD), U8.8 (VCC2), U9.7 (PULL_HIGH1), U9.8 (PULL_HIGH2), U9.17 (VDD), U10.4 (VOUT)
VDD: C1.1, C3.1, C15.1, C29.1, C32.2, J3.7, R9.2, R15.2, R17.2, R25.2, R26.2, U3.5 (VDD), U7.5 (VDD), U8.1 (VCC1), U11.2 (VCC), U12.2
VP_IN: C11.1, R21.1, U4.4 (A), U9.12 (VP)
ZX: U9.1 (ZX)
ZX_I: U9.21 (ZX_I)

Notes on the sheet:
Not Isolated
Isolated
Dual NOT gate
I2C resistor enable
Select polarity
NORM
INV
Analog multiplexer
I2C mode enable for ADE7953
When SCLK and CS are HIGH
Calplug Wattmeter Version 4 - I2C
1.1
Nov 19, 2018
Yongxi Li, Yaxin Deng, Lifeng Liang, Micheal Klopfer

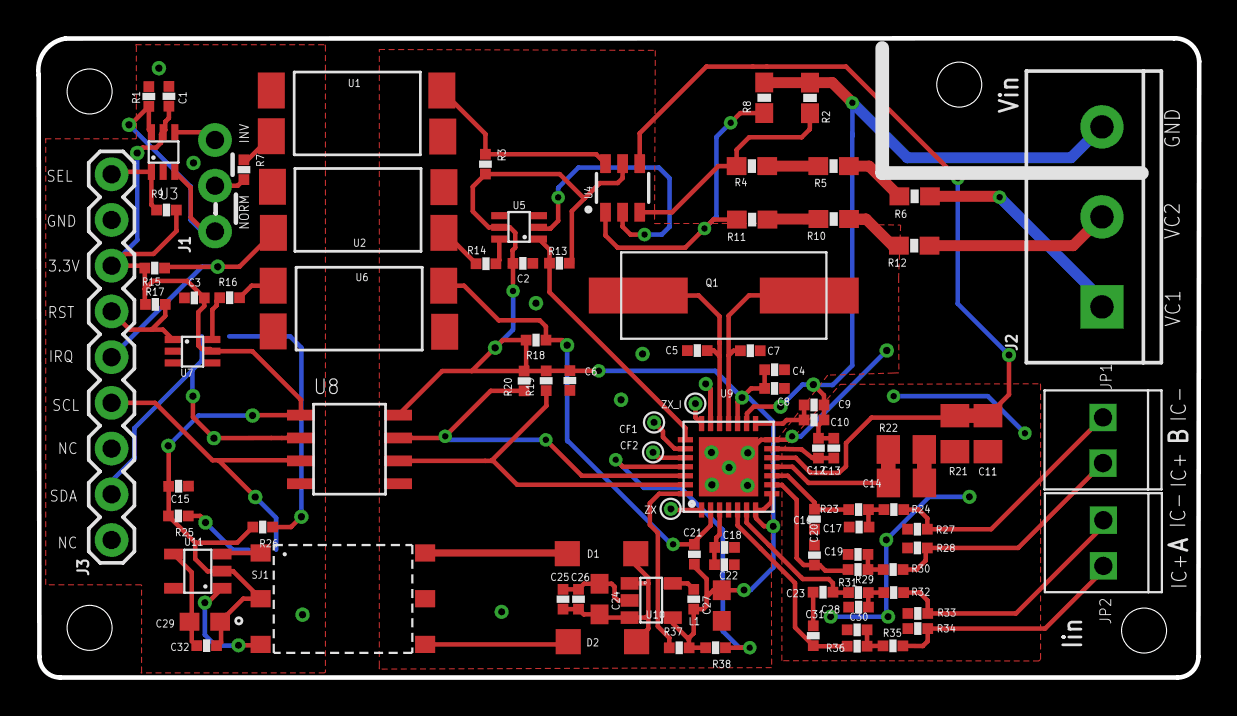
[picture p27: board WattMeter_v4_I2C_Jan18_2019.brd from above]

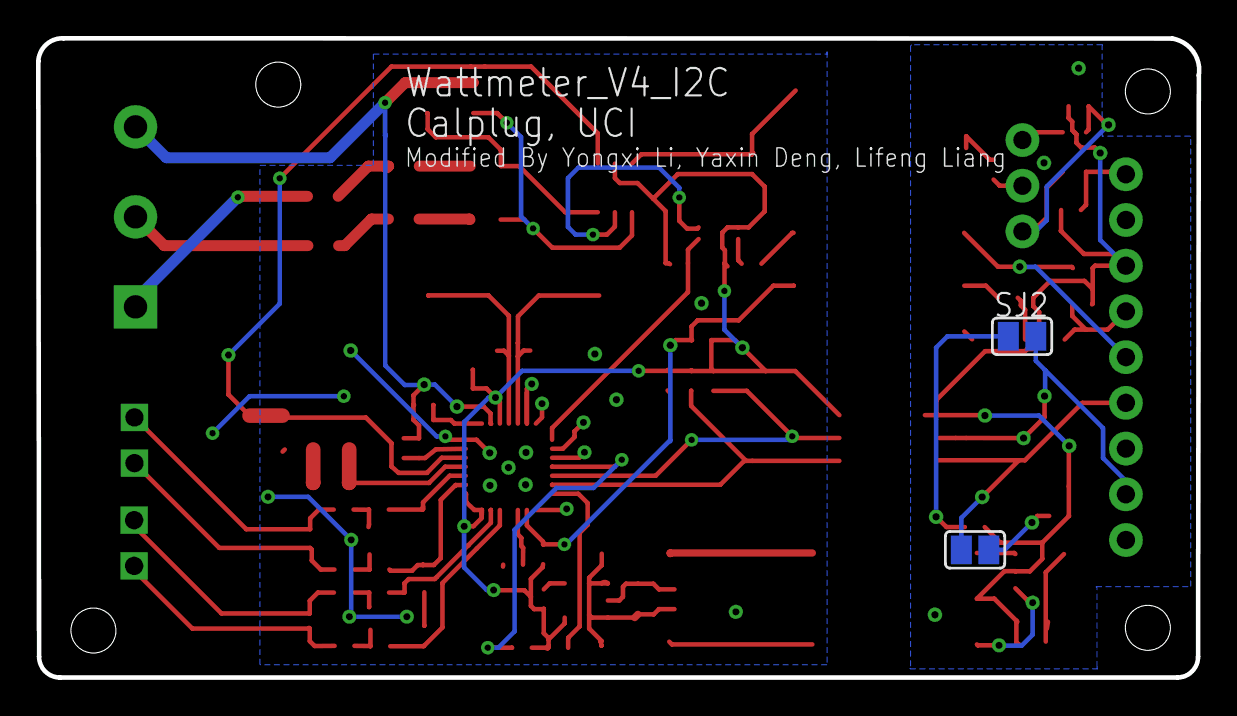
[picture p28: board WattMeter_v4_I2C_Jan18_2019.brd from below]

Board: 2 copper layers, 64.5 x 35.5 mm, 93 parts (2 on the bottom side), 60 nets.

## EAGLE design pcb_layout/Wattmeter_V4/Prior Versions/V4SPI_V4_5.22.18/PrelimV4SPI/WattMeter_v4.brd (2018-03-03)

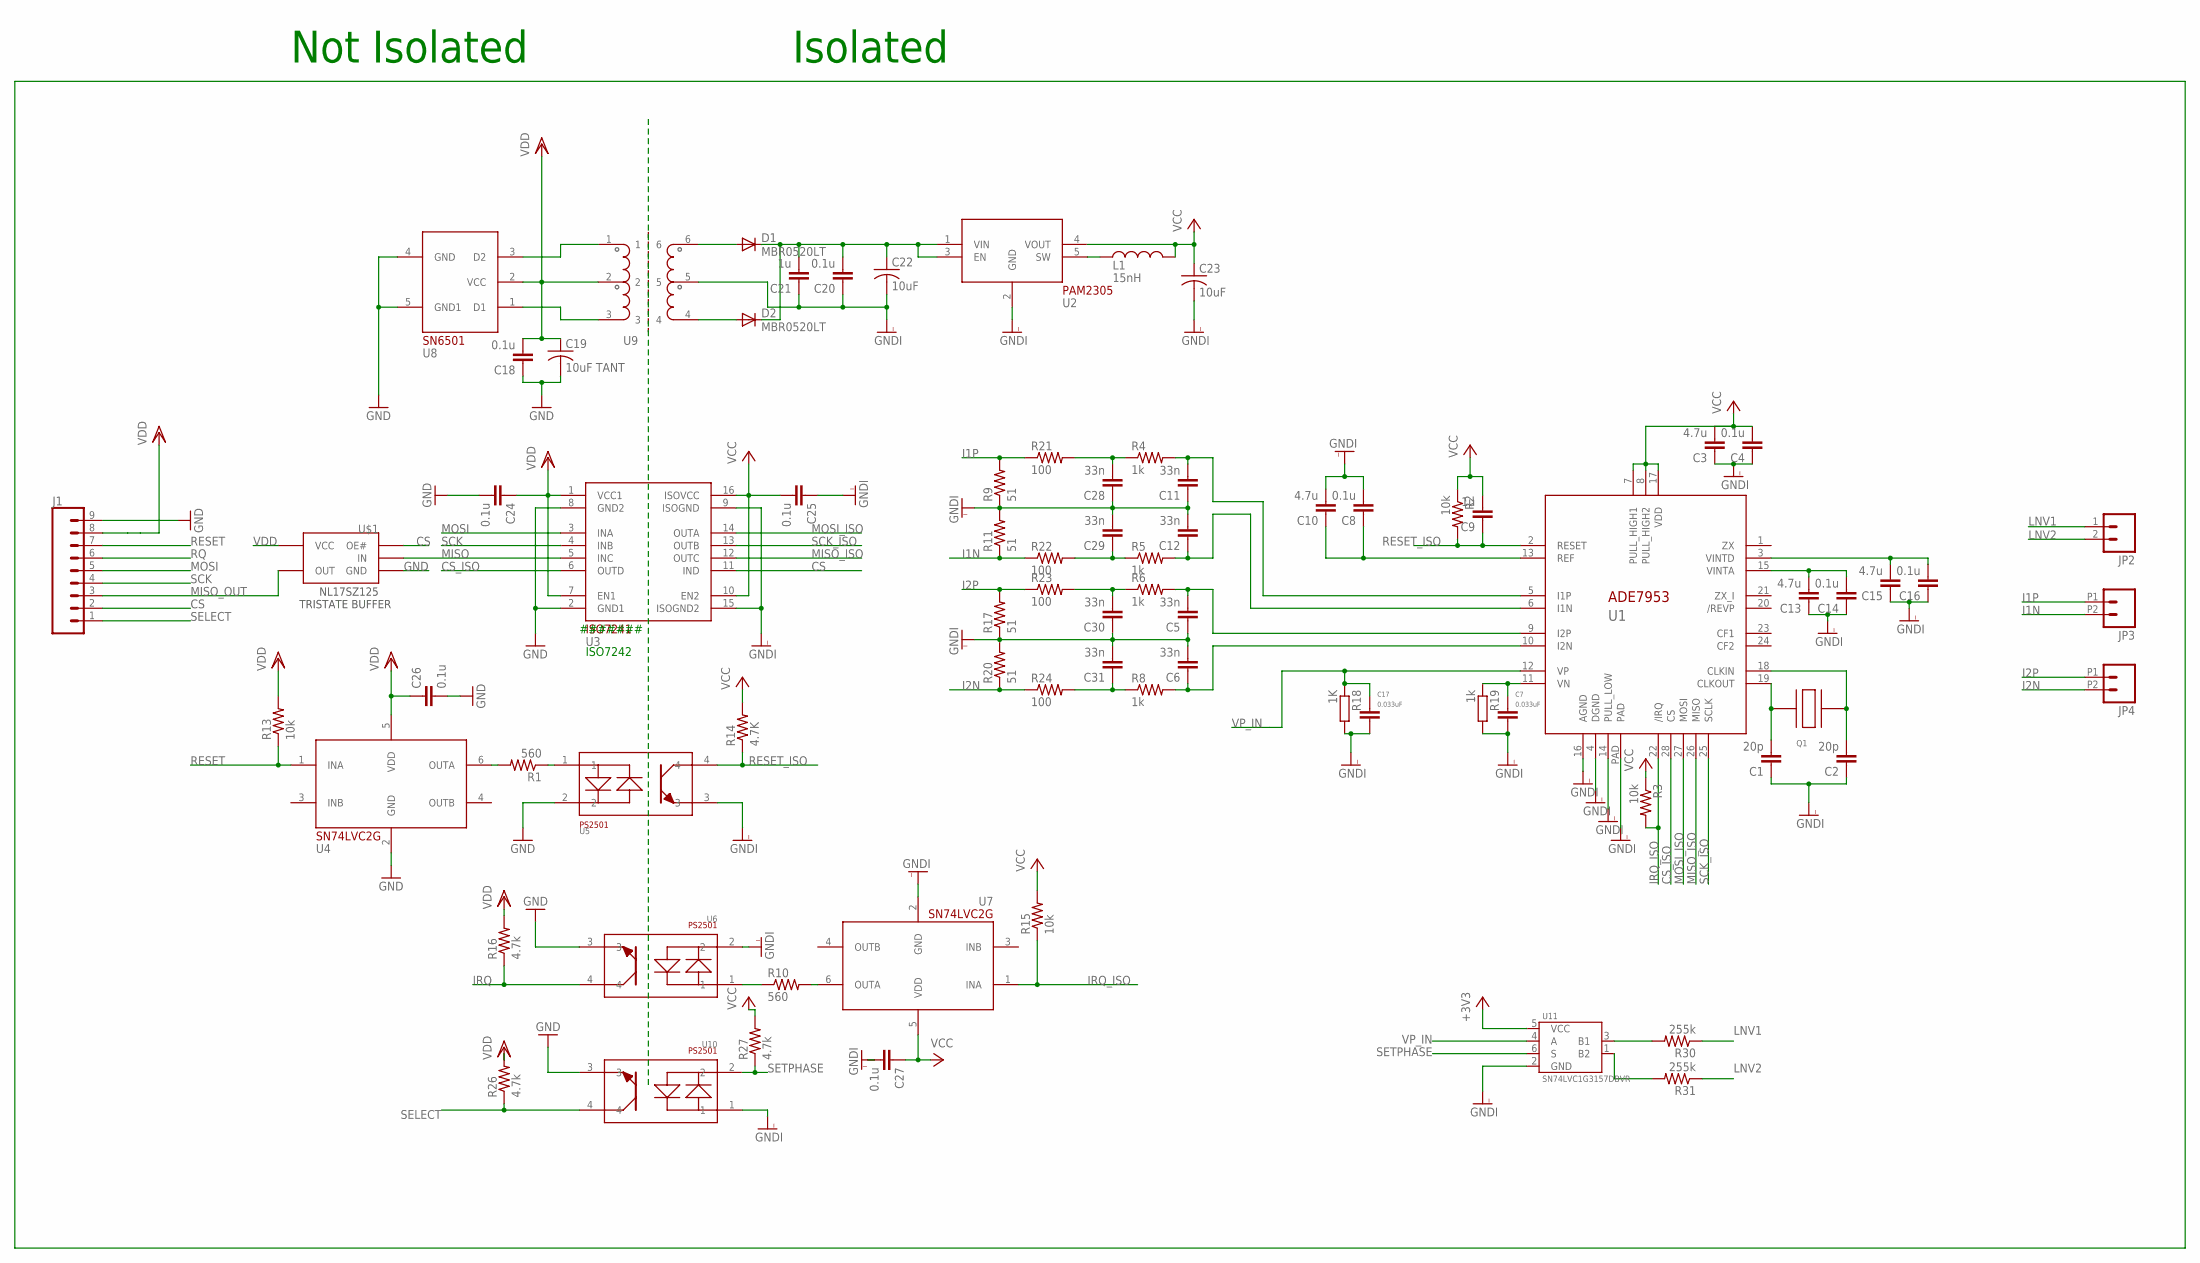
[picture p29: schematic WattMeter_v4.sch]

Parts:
C1, C2: 20p; 0402-CAP
C3, C10, C13, C15: 4.7u; 0402-CAP
C4, C8, C14, C16, C18, C20, C24, C25, C26, C27: 0.1u; 0402-CAP
C5, C6, C11, C12, C28, C29, C30, C31: 33n; 0402-CAP
C7, C17: 0.033uF; C0805K
C9, C21: 1u; 0402-CAP
C19: 10uF TANT; C0603
C22, C23: 10uF; C0603
D1, D2: MBR0520LT; SOD123
J1: CONN_09; 1X09
JP2: M025MM; SCREWTERMINAL-5MM-2
JP3, JP4: M022.54MM_SCREWTERM; 1X02_2.54_SCREWTERM
L1: 15nH; 0402-RES
Q1: QUARTZ_3.58M_2PIN; HC-49S
R1, R10: 560; 0402-RES
R2, R3, R13, R15: 10k; 0402-RES
R4, R5, R6, R8: 1k; 0402-RES
R9, R11, R17, R20: 51; 0402-RES
R14: 4.7K; 0402-RES
R16, R26, R27: 4.7k; 0402-RES
R18: 1K; C0805K@1
R19: 1k; C0805K@1
R21, R22, R23, R24: 100; 0402-RES
R30, R31: 255k; 0402-RES
U1: ADE7953; 28-WFQFN
U2: PAM2305; TSOT25
U3: ISO7241; 16-SOIC
U4, U7: SN74LVC; DCKT
U5, U6, U10: PS2505; 4-SMD
U8: SN6501; SOT-23-5
U9: TRANSFO_3.3
U11: SN74LVC1G3157DBVR; SOT-23-6
U$1: BUFFER-NL17SZ125; TSOP-5

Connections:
+3V3: U11.5 (VCC)
CS: J1.2, U3.11 (IND), U$1.1 (OE#)
CS_ISO: U1.28 (CS), U3.6 (OUTD)
GND: C18.1, C19.2, C24.2, C26.2, J1.9, U3.2 (GND1), U3.8 (GND2), U4.2 (GND), U5.2, U6.3, U8.4 (GND), U8.5 (GND1), U10.3, U$1.3 (GND)
GNDI: C1.1, C2.1, C3.1, C4.1, C5.1, C6.2, C7.2, C8.2, C10.2, C11.1, C12.2, C13.1, C14.1, C15.1, C16.1, C17.2, C20.1, C21.1, C22.2, C23.2, C25.1, C27.2, C28.1, C29.2, C30.1, C31.2, R9.1, R11.2, R17.1, R18.2, R19.2, R20.2, U1.4 (DGND), U1.14 (PULL_LOW), U1.16 (AGND), U1.PAD, U2.2 (GND), U3.9 (ISOGND), U3.15 (ISOGND2), U5.3, U6.2, U7.2 (GND), U9.5, U10.1, U11.2 (GND)
I1N: JP3.P2 (2), R11.1, R22.1
I1P: JP3.P1 (1), R9.2, R21.1
I2N: JP4.P2 (2), R20.1, R24.1
I2P: JP4.P1 (1), R17.2, R23.1
IRQ: R16.1, U6.4
IRQ_ISO: R3.2, R15.1, U1.22 (/IRQ), U7.1 (INA)
LNV1: JP2.1, R30.1
LNV2: JP2.2, R31.1
MISO: U3.5 (INC), U$1.2 (IN)
MISO_ISO: U1.26 (MISO), U3.12 (OUTC)
MISO_OUT: J1.3, U$1.4 (OUT)
MOSI: J1.5, U3.3 (INA)
MOSI_ISO: U1.27 (MOSI), U3.14 (OUTA)
unnamed: C1.2, Q1.1, U1.19 (CLKOUT)
unnamed: C2.2, Q1.2, U1.18 (CLKIN)
unnamed: C7.1, R19.1, U1.11 (VN)
unnamed: L1.1, U2.5 (SW)
unnamed: C8.1, C10.1, U1.13 (REF)
unnamed: C13.2, C14.2, U1.15 (VINTA)
unnamed: C12.1, R5.2, U1.6 (I1N)
unnamed: C11.2, R4.2, U1.5 (I1P)
unnamed: C15.2, C16.2, U1.3 (VINTD)
unnamed: R30.2, U11.3 (B1)
unnamed: D1.A, U9.6
unnamed: C20.2, C21.2, C22.1, D1.C, D2.C, U2.1 (VIN), U2.3 (EN)
unnamed: D2.A, U9.4
unnamed: U8.3 (D2), U9.1
unnamed: R31.2, U11.1 (B2)
unnamed: U8.1 (D1), U9.3
unnamed: C28.2, R4.1, R21.2
unnamed: R1.1, U5.1
unnamed: R1.2, U4.6 (OUTA)
unnamed: C29.1, R5.1, R22.2
unnamed: C6.1, R8.2, U1.10 (I2N)
unnamed: R10.1, U6.1
unnamed: R10.2, U7.6 (OUTA)
unnamed: C5.2, R6.2, U1.9 (I2P)
unnamed: C30.2, R6.1, R23.2
unnamed: C31.1, R8.1, R24.2
RESET: J1.7, R13.1, U4.1 (INA)
RESET_ISO: C9.1, R2.2, R14.1, U1.2 (RESET), U5.4
RQ: J1.6
SCK: J1.4, U3.4 (INB)
SCK_ISO: U1.25 (SCLK), U3.13 (OUTB)
SELECT: J1.1, R26.1, U10.4
SETPHASE: R27.1, U10.2, U11.6 (S)
V2P: C17.1, R18.1, U1.12 (VP)
VCC: C3.2, C4.2, C9.2, C23.1, C25.2, C27.1, L1.2, R2.1, R3.1, R14.2, R15.2, R27.2, U1.7 (PULL_HIGH1), U1.8 (PULL_HIGH2), U1.17 (VDD), U2.4 (VOUT), U3.10 (EN2), U3.16 (ISOVCC), U7.5 (VDD)
VDD: C18.2, C19.1, C24.1, C26.1, J1.8, R13.2, R16.2, R26.2, U3.1 (VCC1), U3.7 (EN1), U4.5 (VDD), U8.2 (VCC), U9.2, U$1.5 (VCC)
VP_IN: U11.4 (A)

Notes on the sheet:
Not Isolated
Isolated
ISO7242
#######

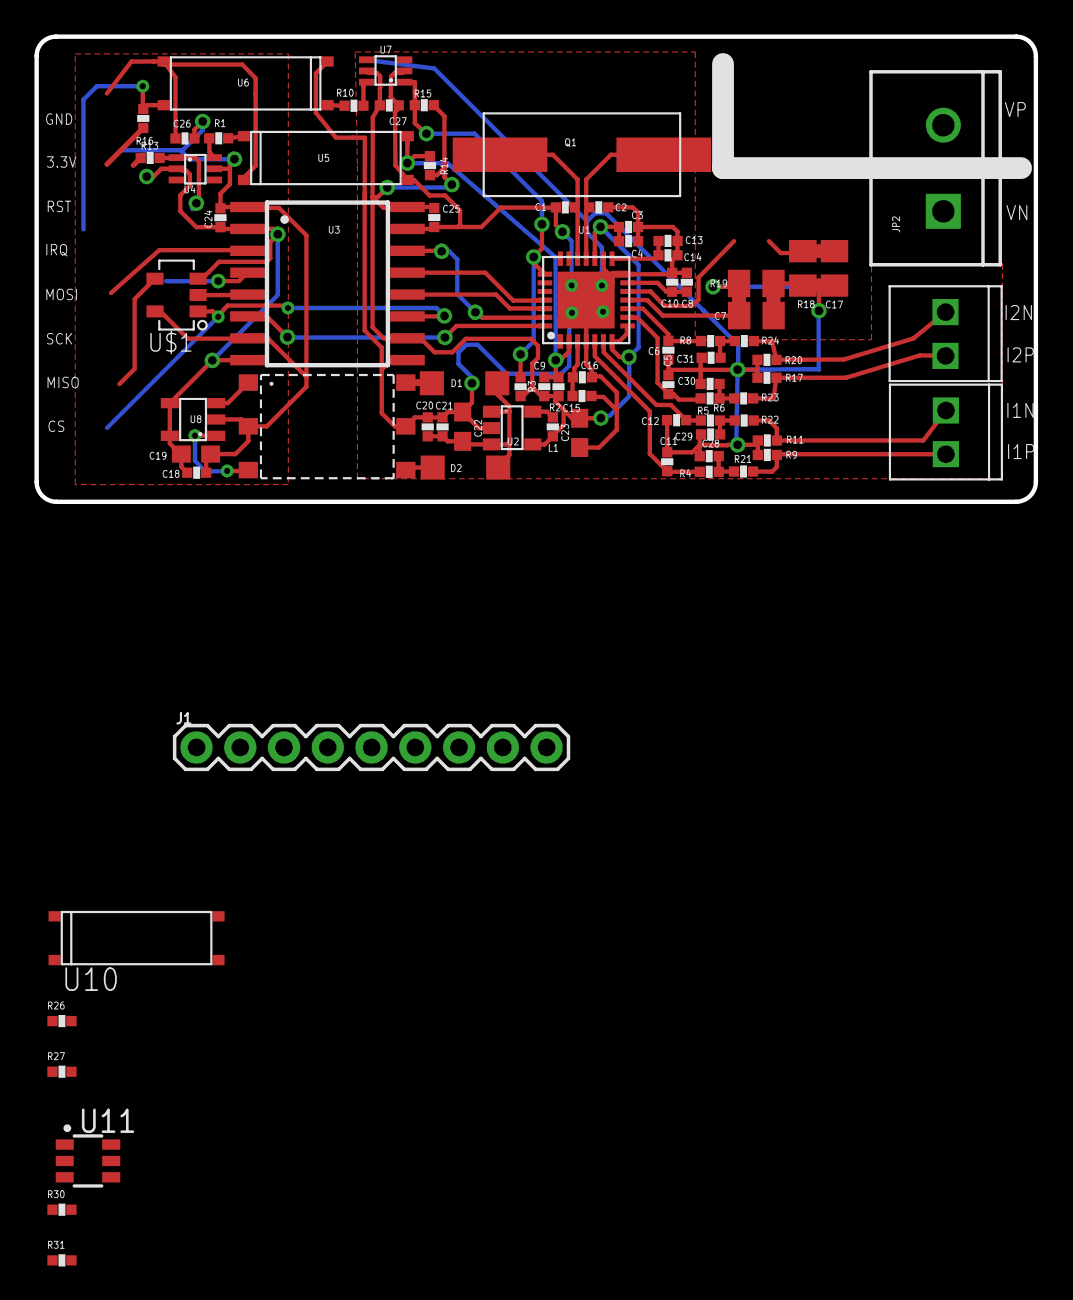
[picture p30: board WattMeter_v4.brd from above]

Board: 2 copper layers, 58.0 x 27.0 mm, 77 parts (0 on the bottom side), 52 nets.

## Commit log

2017-11-07 Add files via upload
    Updated Wattmeter board to solve population issues with components touching and to add in a tri-state buffer to avoid SPI bus "hogging"
    [WattMeterBOM_v3.xlsx, WattMeter_v3.brd, WattMeter_v3.sch]
2018-03-03 Add files via upload
    wattmeter_V4
    [WattMeter_v4.brd, WattMeter_v4.sch]
2018-04-15 Updated V4 board
    [WattMeter_v4.brd, WattMeter_v4.sch]
2018-05-01 latest updates for I2C and SPI
    [WattMeter_v4.brd, WattMeter_v4.sch, WattMeter_v4_I2C.brd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]
2018-05-14 Update with ESP32 Code
    [WattMeterBOM_v3.xlsx, WattMeter_v2.brd, WattMeter_v2.sch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]
2018-05-14 ESP32 Update
2018-05-22 File Upload
    [WattMeter_v3.1.brd, WattMeter_v3.1.sch, WattMeter_v4.brd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]
2018-05-22 Update Folder Structure
    [WattMeterBOM_v3.xlsx, WattMeter_v2.brd, WattMeter_v2.sch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]
2018-05-25 Arduino I2C library for ADE7953.
2018-05-25 Add files via upload
    Updated Arduino demo for ADE7953 by using I2C library
2018-05-31 Update Repository Structure
    [WattMeterBOM_V4_I2C.xlsx, WattMeterBOM_v3.xlsx, WattMeter_v2.brd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]
2018-06-01 Updated Schematic and Layouts for V4
2018-10-26 Update I2C Info
2018-11-20 Update folders with PCB error correction
    [WattMeterBOM_V4_I2C.xlsx, WattMeter_v4.brd, WattMeter_v4.sch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]
2018-12-04 Update I2C Libs
2019-02-22 Update ESP32 Library
2019-02-22 Update ESP32 Library for Initial Release @ v. 1.0
2019-02-24 fix naming bug in PowerFactor calibration

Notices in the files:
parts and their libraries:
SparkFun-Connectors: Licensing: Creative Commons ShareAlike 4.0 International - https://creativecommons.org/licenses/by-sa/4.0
